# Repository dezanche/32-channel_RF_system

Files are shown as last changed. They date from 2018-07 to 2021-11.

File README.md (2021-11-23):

The 32-Channel RF Signal Amplifier and Attenuator System is a modular amplifier and attenuation system designed to provide 2nd stage amplification in close proximity to an MRI scanner. With proper choice of components it can readily be adapted to a wide range of Larmor frequencies and applications. Each channel’s amplifier and attenuator circuitry is housed on a separate daughterboard for flexibility and easy servicing.
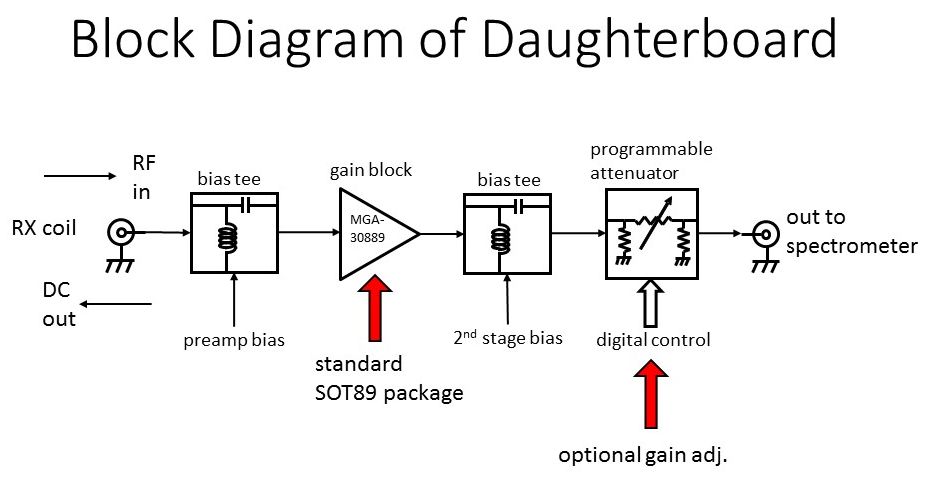
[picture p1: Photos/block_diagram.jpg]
block diagram

These Daughterboards stand perpendicular to a larger Motherboard which contains all the common circuitry such as power distribution and protection circuitry, as well as the interface for attenuation control.
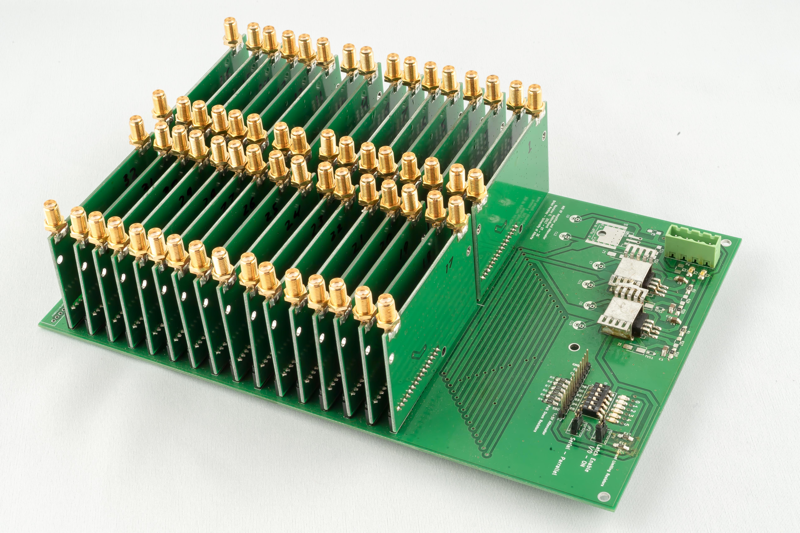
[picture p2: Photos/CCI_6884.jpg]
assembled boards

Additional information is provided in [this YouTube video](https://www.youtube.com/watch?v=jpFOpedchC8).

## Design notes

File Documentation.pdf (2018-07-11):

32-channel RF System | 1 | 2018-07-11

# 32-Channel RF Signal Amplifier and Attenuator System

## Design and Theory of Operation

## © 2018 Brian D. Markley and Nicola De Zanche University of Alberta

### Table of Contents

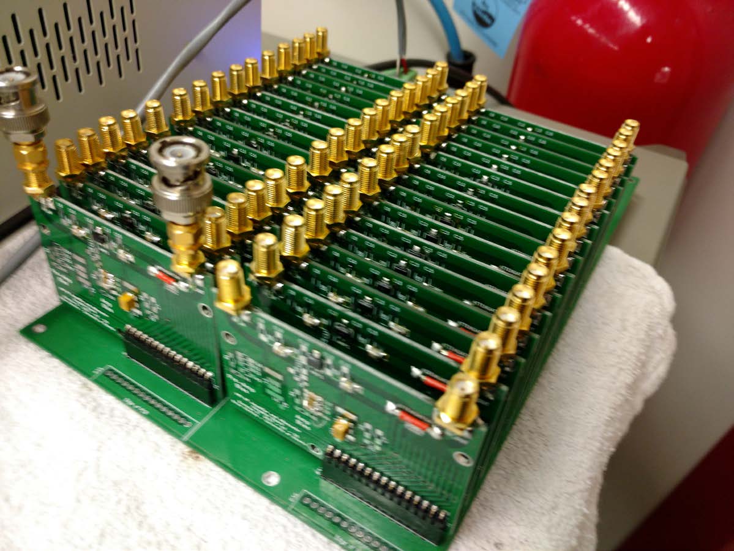
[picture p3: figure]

32-channel RF System | 2 | 2018-07-11

## Introduction

The 32-Channel RF Signal Amplifier and Attenuator System is a modular amplifier and attenuation system designed to provide 2nd stage amplification in close proximity to a 4.7 T MRI scanner (at a Larmor frequency
of 200 MHz). With proper choice of
components it can readily be adapted
to a wide range of other frequencies and applications. Each channel’s amplifier and attenuator circuitry is housed on a separate daughterboard for flexibility and easy servicing.
These | Daughterboards | stand
perpendicular | to | a | larger
Motherboard which contains all the common circuitry such as power distribution and protection circuitry, as well as the interface for attenuation control (Figure 1).

## License and Disclaimer

This open-source hardware design is licensed under the terms of the CERN
Open Hardware Licence v1.2 (https://www.ohwr.org/licenses/cern-ohl/license_versions/v1.2) (see also
License below). Specifically, the
design is provided “as is”, with no express or implied warranty, and the Licensor shall not be held liable for any damages resulting from the use of the design information.
The static magnetic field of the MRI scanner can cause dangerous forces on ferromagnetic materials. The instructions contained in this document require familiarity with MRI electronics and with the MRI environment. Standard precautions for working with such equipment must be followed. Specifically, all materials, tools and components used in construction must be non-magnetic if they are to be used within the MRI suite.

## Design

Principle of Operation
The 32-Channel RF Signal Amplifier and Attenuator System is designed to provide, for each channel, RF amplification using a single device (gain block), followed by an optional programmable attenuator to allow the signal level to be adjusted depending on the requirements of the subsequent stage (in this case the MRI scanner’s spectrometer). The design is modular, expandable and readily serviceable by using a separate board for each channel, laid out in an array on a single backplane (motherboard). The use of separate boards also provides high isolation (low crosstalk) between channels. A block diagram of one RF channel is shown in Figure 2.
The Motherboard distributes power and sets the attenuator states of up to 32 Daughterboards. Multiple motherboards can be daisy-chained if more than 32 channels are needed, taking care not to exceed the maximum current limits. Depending on the

Figure 1: The 32-Channel RF Signal Amplifier and Attenuator System. Note the daughterboard modules assembled in an array attached to the motherboard.

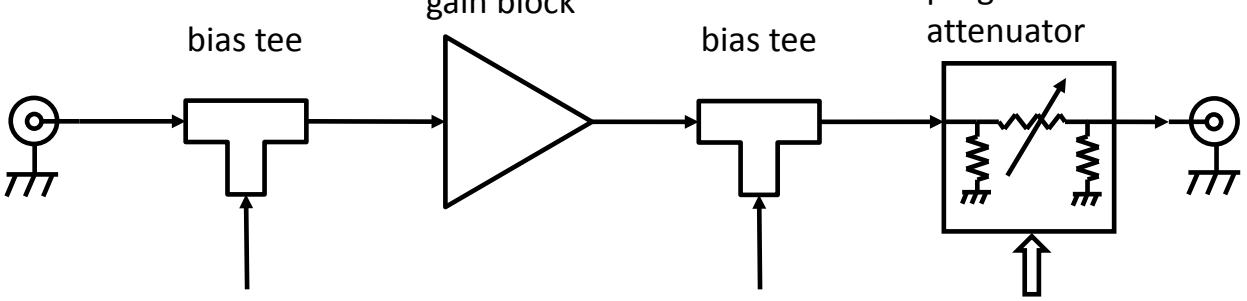
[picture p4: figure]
bias tee; attenuator

32-channel RF System | 3 | 2018-07-11

application’s requirements and component selection, some components (marked “optional” on the schematics) may be omitted. Board design follows IPC standards [1].

Motherboard
The motherboard contains all the power and control inputs for the amplifiers and attenuators. The daughter boards interface with the motherboard using female 2.54 mm straight pin headers on the motherboard and male 2.54 mm right-angle headers on the daughterboard. The motherboard is a 1.6 mm thick two-layer FR4 printed circuit board (PCB), plated with 2 ounce copper (70 µm) to limit the resistance of the traces. Schematics are shown in Figure 3 and Figure 4. The PCB layout is shown in Figure 5.

### Power

Power for 3 separate DC rails is provided through a 4-pin connector (P1). The rails supply, respectively, the RF amplifiers, attenuators, and optional external 1st stage amplifiers (e.g., for preamps at the RF coil) through a bias voltage at RF input of each DaughterBoard.
In our application the rails are all 5 volts, fed by an external 6.5 volt power supply, which is located outside of the MRI scanner room. Each power input is protected by 1 A resettable fuses (F1–F3), and if desired can be regulated (in our case to 5 volts) using 1084 voltage regulators (U1–U6, dual footprints are provided depending on package choice). The power regulators must be adequately heat-sinked to prevent failure. The design includes holes for bolt-on heat sinks as well as footprints for surface mount heat sinks on both the front and back of the board.
Capacitors (C1–C12) and resistors (R27–R32) for the power regulators must be used according to the regulator’s documentation. Additional footprints are provided on the board for optional power filtering components. Redundant footprints for both through-hole and surface-mount components are available on the PCB for flexibility in component choice and implementation.
Protection against overvoltage and electrostatic discharge (ESD) is provided by Zener (Z1–Z3) and transient-voltage-suppression (TVS) diodes (TVS1–TVS3), respectively [2]. Reverse polarity protection can be provided at the input of the voltage regulator by shunting to ground using an appropriately-rated reverse polarity diode. If the polarity is correct the diode will

Figure 2: Block diagram of one channel of the RF amplifier and attenuator system. RF signal flow is left to right.

gain block | programmable
preamp bias | 2nd stage bias | digital control

32-channel RF System | 4 | 2018-07-11

carry negligible current, but if polarity is reversed it will shunt current to ground, activating the fuse and protecting components downstream.

### Control

The control and interface components for the SKY12347-362LF attenuators are located on the motherboard. Manual control of these 6 bit attenuators is provided by 6 SPST switches (DIP1) and on-board jumpers for the latch enable (LE, JP1) and parallel-serial (P/S, JP2) interface selection. Remote attenuator control is available via a parallel or serial interface through the header (P2) located above the attenuator control switches.
Due to limitations in the P/S selection of the attenuator, parallel operation of the chip requires that the LE pin be switched high (5 V) after the power to the chip is brought high. To accommodate this, the current limiting resistor for the LE pin (R18) should use a large value (e.g., 1 MΩ) to provide a time delay on the LE pin. In this configuration the attenuator bits are set directly by either manual control with the motherboard switches, or – with the switches in the off position – remotely using the attenuator control header (P2) on the motherboard located above the switches.
Alternatively, remote control of the attenuator state can be controlled using a serial interface, by setting the P/S pin high and following the manufacturer’s documentation. The serial interface has the additional advantage of providing feedback of the attenuator state to a computer using the Serial Out pin (SO). This remote attenuation is not provided, but would be easily implemented with a separate module connected to the attenuator control header (P2).

### LED Indicators

The status of each power rail and attenuator bit is indicated using low-current LEDs (D1–D9) in series with resistors (R1–R9).

### Expandability

Multiple motherboards may be daisy-chained using the headers at the bottom edge of the PCB (P35 and P36) to expand the design to accommodate additional channels. If this is done, each PCB should be fed its power separately and only the attenuator circuitry should be interconnected. Maximum current on the attenuator traces is 1 A, and may need to be appropriately fused in case an accidental fault should occur.

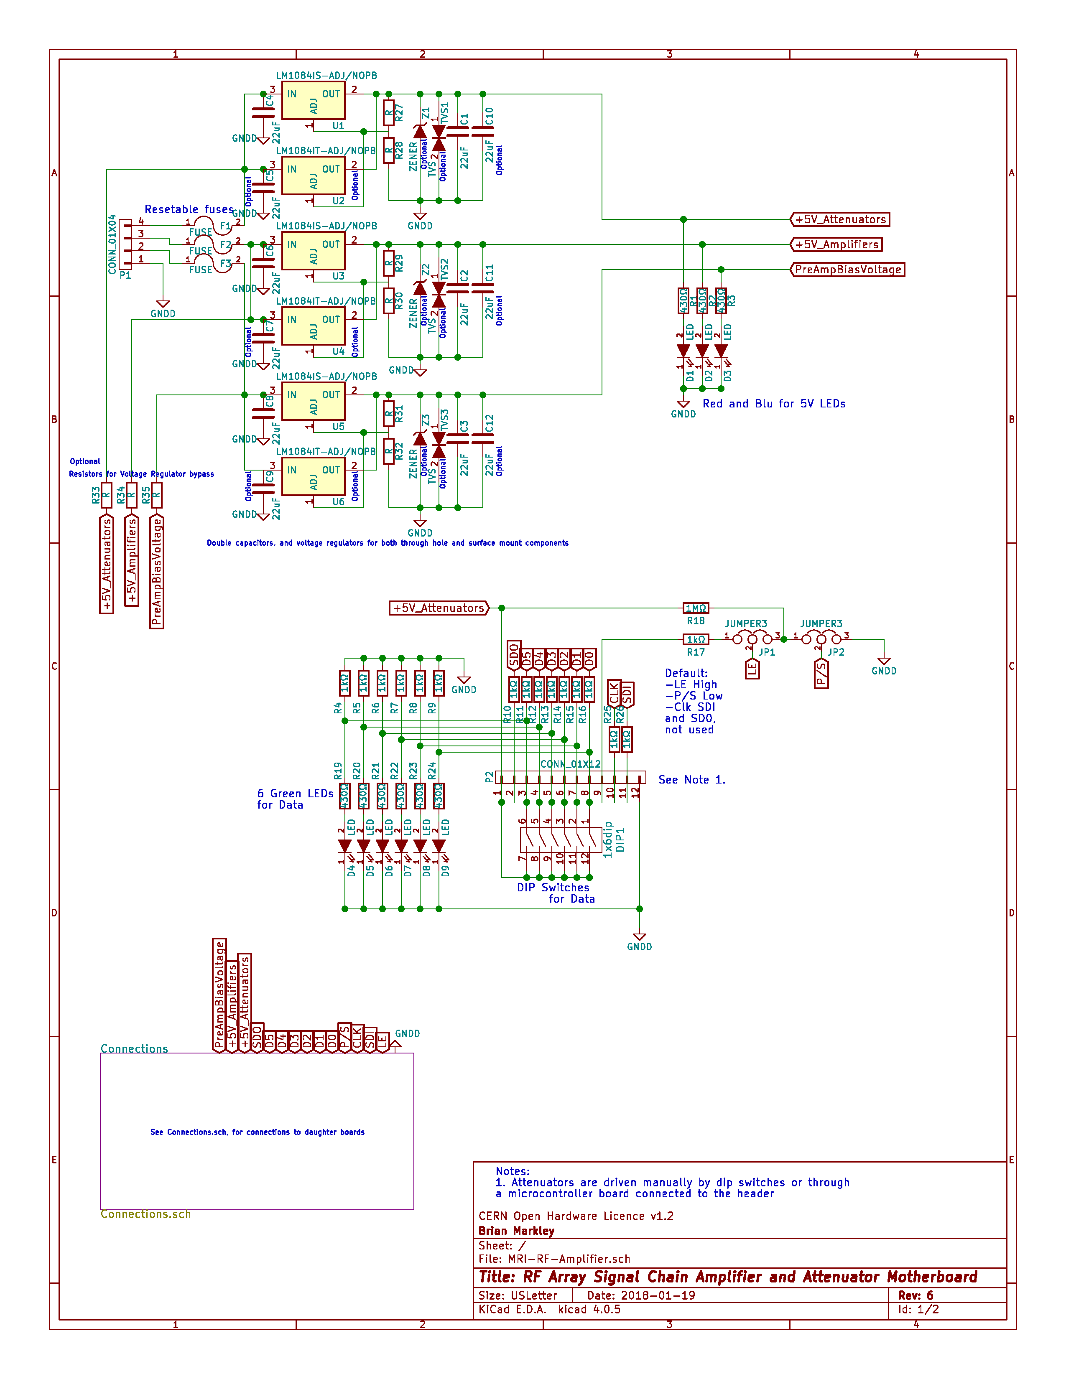
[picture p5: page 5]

32-channel RF System | 5 | 2018-07-11

Figure 3: Schematic of Motherboard power (top) and attenuator control circuitry (middle).

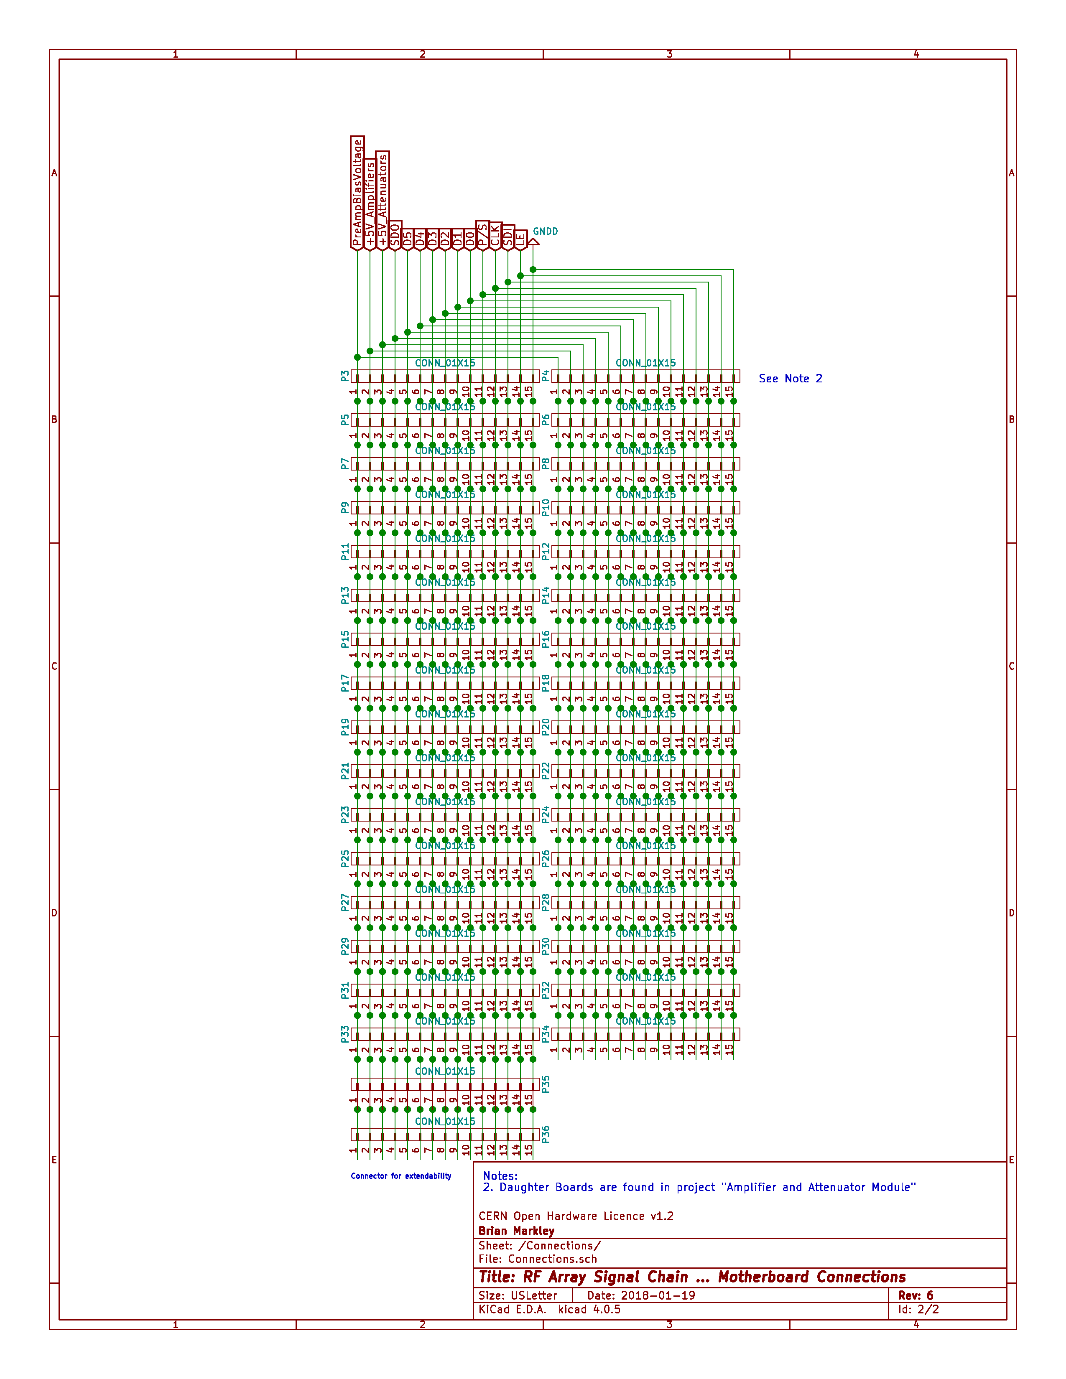
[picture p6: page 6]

32-channel RF System | 6 | 2018-07-11

Figure 4: Schematic of the Motherboard header array.

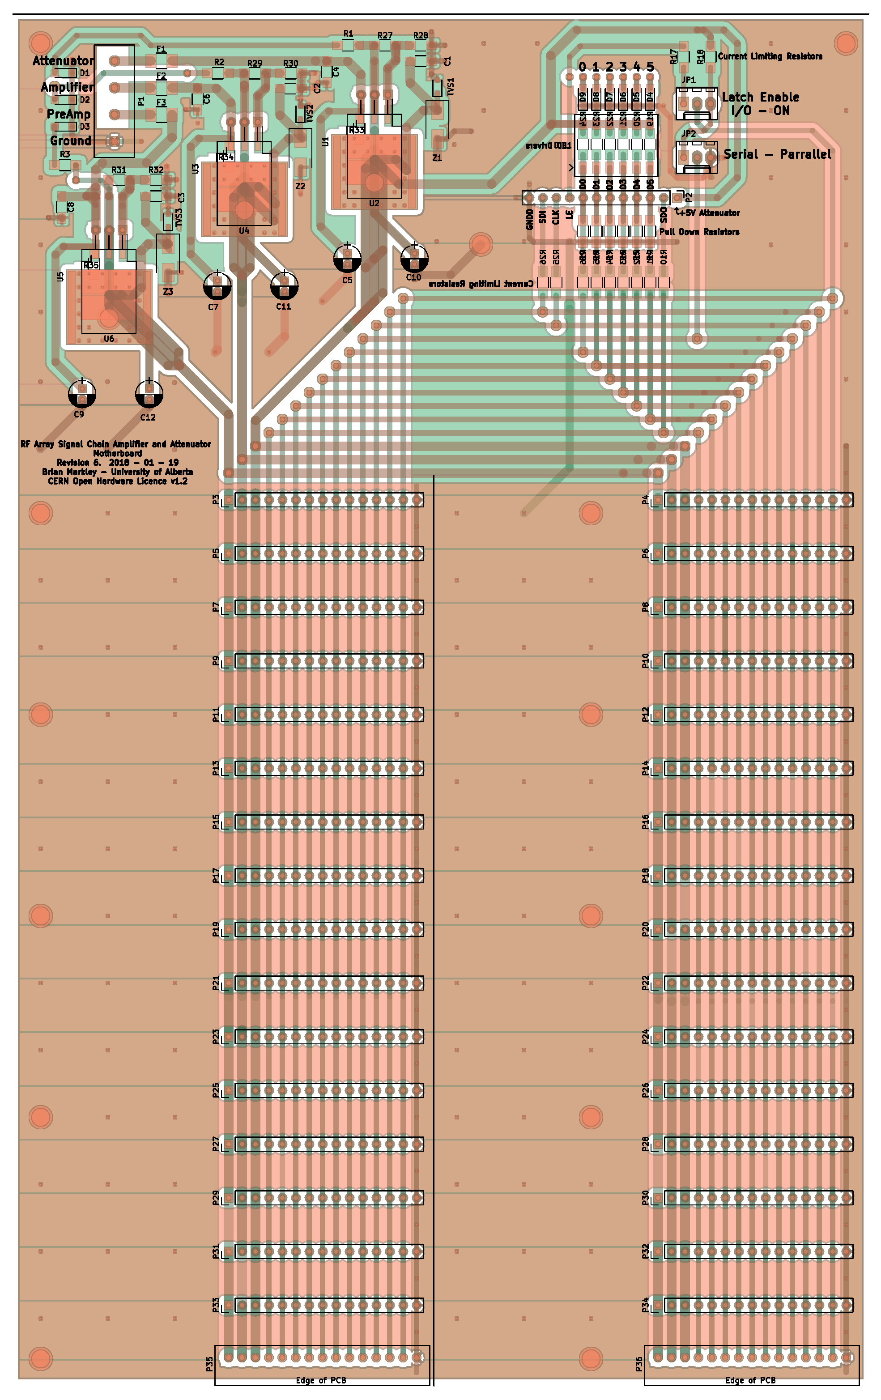
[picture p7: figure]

32-channel RF System | 7 | 2018-07-11

Figure 5: Motherboard PCB layout.

32-channel RF System | 8 | 2018-07-11

Daughterboards
Each daughterboard contains an amplifier (gain block) and attenuator, as well as a bias tee for providing DC bias to an external 1st stage amplifier (preamp). To minimize PCB cost from our supplier, the design includes two identical boards on a standard half eurocard size (80 mm × 100 mm), with a v-score where they can be separated. The PCB is a two-layer design on a 1.6 mm thick FR4 substrate with 1 ounce copper (35 µm). The schematic and the PCB layout are included in Figure 6 and Figure 7, respectively.

### RF Transmission Line

A coplanar waveguide with ground was used with the grounds designed to act primarily as a shielding element. The gap between the ground and RF line is 3.0 mm, and the RF line is 3.0 mm wide, which produces a transmission line with a characteristic impedance of 50 Ω, at 200 MHz (calculated using the transmission line calculator included with KiCAD). Using a separate board for each channel ensures that the length and shape of the transmission lines, and thus frequency and phase response for each channel, are identical. Input and output RF connections on each board can be made using a variety of end-launch coaxial connectors (RF1 and RF2) for 1.6 mm boards such as SMA.

### Amplification

Broadcom MGA-30889 amplifiers (AMP1) were selected for this design due to their high gain, and stability with a relatively low noise figure [3]. This device is now listed as “end-of-life” and will become obsolete. However, by using a standard SOT89-3 package, a wide variety of alternate amplifiers (gain blocks) is available for replacement. If the system is to be used in a location with significant static magnetic field (B0), the amplifiers’ performance should be measured in such conditions to ensure adequate performance. In many cases it is sufficient to rotate the orientation of the amplifiers relative to B0 to restore performance equivalent to the zero-field case. Footprints for optional components are available to allow for filtering and matching needs of various amplifiers that use the SOT89 footprint. Pads for low-current LEDs (D1–D3) and associated current-limiting resistors (R1, R4, R5) are provided to allow visual confirmation of power states if desired.

### Bias Tees

The amplifiers are powered using a DC bias tee (L3 or L4 and neighboring capacitors) to inject DC into the RF output pin. A pre-amplifier located closer to the MRI RF coil may also be powered through the optional pre-amp DC bias tee (L1 or L2 and neighboring capacitors), upstream from the on-board amplifier. If possible, inductors should be chosen to have a self-resonance frequency (SRF) close to the Larmor frequency of operation. Like all other components in the design, inductors for the DC bias tees must be air-core, phenolic-core, or other non-magnetic types if they are to be exposed to the static magnetic field of the MRI scanner. Those containing ferromagnetic materials will saturate and present a much lower inductance than the nominal value.

### Attenuation

A 6-bit SKY12347-362LF attenuator¹ (ATTENUATOR1) was selected for the design due to its relatively economical cost and 31.5 dB range of operation with 0.5 dB resolution [4]. This robust chip is controllable by either a serial or parallel interface. For parallel use the jumpers

1 currently listed by the manufacturer as “not recommended for new designs”. A drop-in alternate device has not been found.

32-channel RF System | 9 | 2018-07-11

on the motherboard need to be set to parallel mode (P/S pin set low) and the latch enable to ON (LE pin set high) as described in Control. The design may also be implemented without attenuators by soldering a short insulated wire across the attenuator’s footprint to join input and output RF traces. This was done on the prototype with good results.

### Interfacing and Mounting

The attenuator control and power connections interface with the Motherboard using a right-angle male 2.54 mm header (P1). The RF signal input and output interface to coaxial cables using end-launch connectors such as SMA or others having similar footprints. Note that forces on these connectors can be enough to displace the daughterboards because the header alone is not rigid enough to provide strong mounting. Therefore, it is recommended that additional mechanical supports be provided using the mounting holes or using bulkhead-type RF connectors secured to a plate that is perforated to accommodate all 64 RF connections. Care should also be taken to ensure that the daughterboards are not mated to the motherboard in the reverse orientation or with only a partial number of pins inserted (e.g., headers shifter by 1). No protection is provided against mating errors and damage may result to the Motherboard and/or Daughterboards.

### Futureproofing

The design is meant to be flexible so that the boards can be easily swapped out for maintenance or modification. Likewise, the daughterboard could be used independently of the motherboard as a single-channel device, although it may require power and protection circuitry external to the board. The amplifier SOT89 package is very common for gain blocks available from a variety of manufacturers, thus providing ample flexibility to the design. However, the QFN footprint of the attenuator is not commonly used – and there appears to be no drop-in replacement for this component. For this reason the daughterboard design may need to be modified for a different attenuator or if the current one becomes obsolete and is replaced with a newer model.

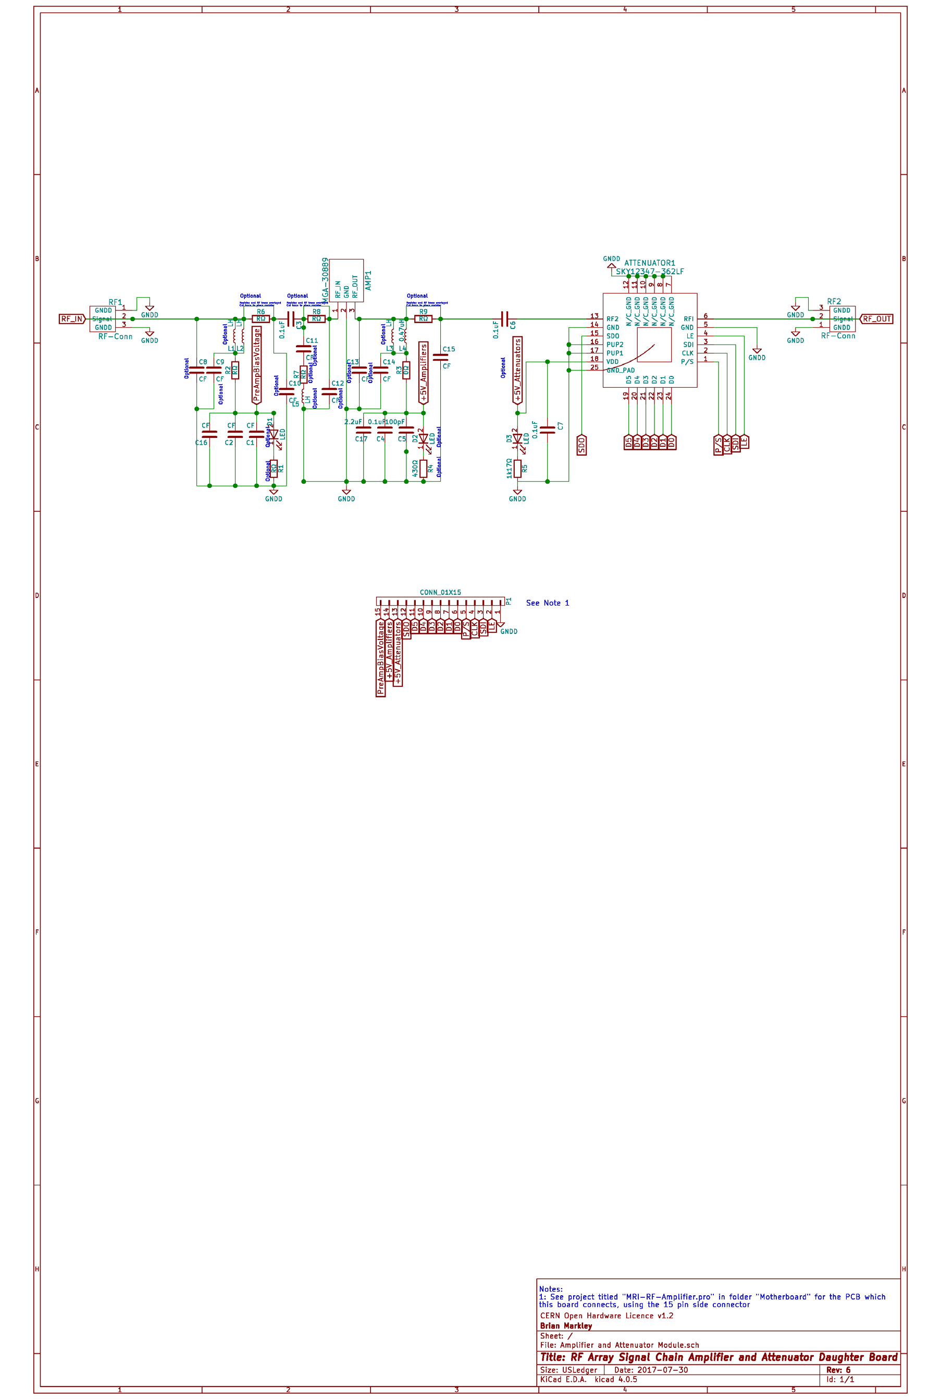
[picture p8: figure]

32-channel RF System | 10 | 2018-07-11

Figure 6: Schematic of the Daughterboards.

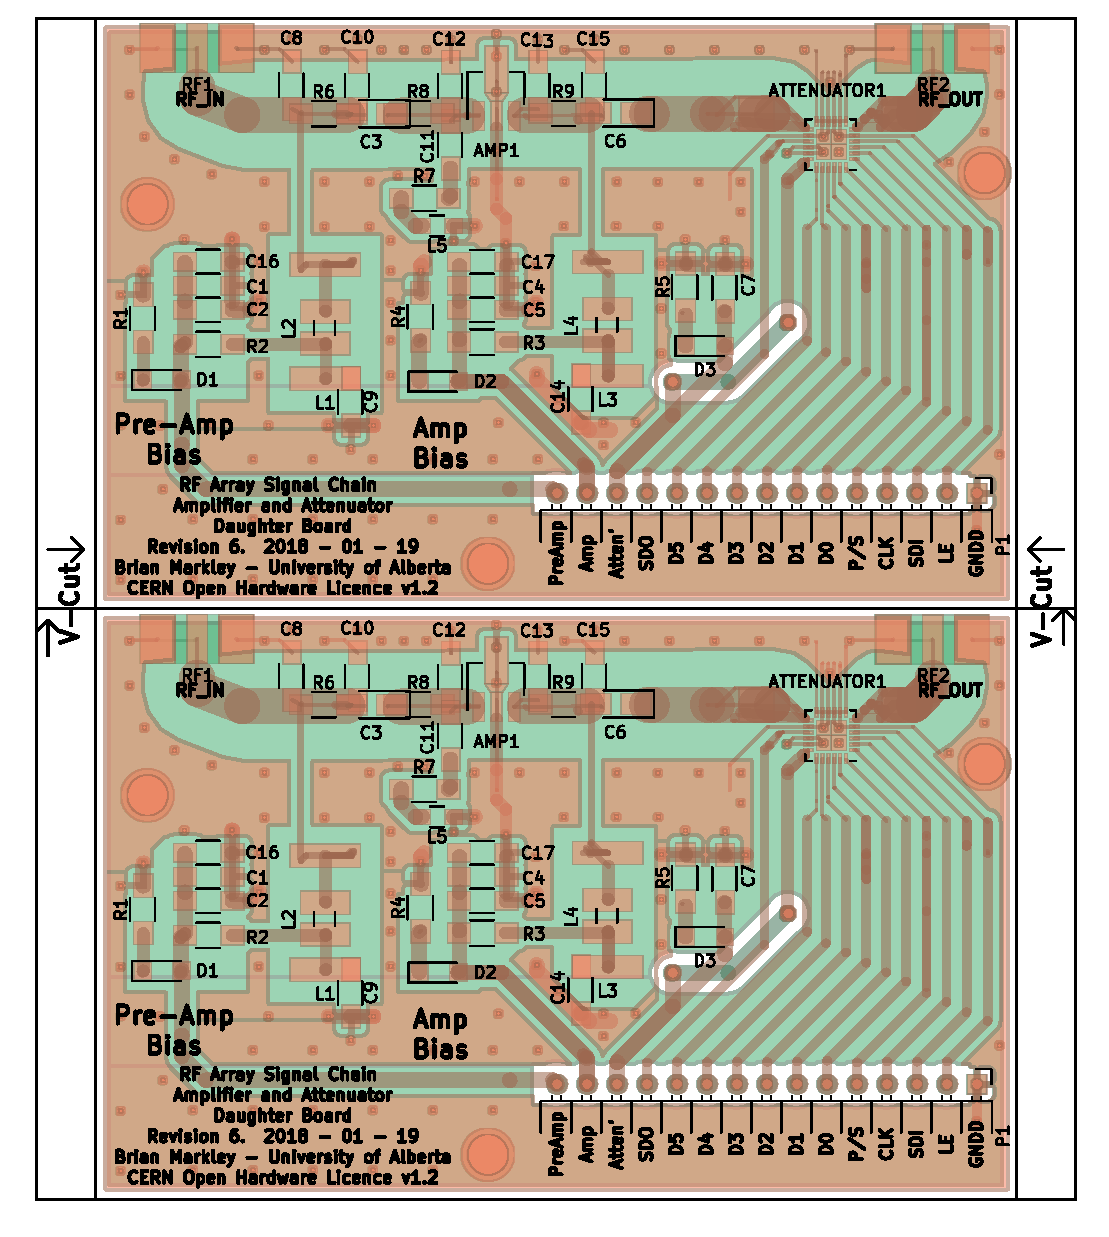
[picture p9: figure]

32-channel RF System | 11 | 2018-07-11

Figure 7: PCB Layout of Daughterboards.

32-channel RF System | 12 | 2018-07-11

## Performance as Built

The following tables summarize the performance of the system as built using the listed components. Performance using different components will vary.
Absolute Maxima
Amplifier and Attenuator Voltage MotherBoard | 7 | volts
Amplifier Current MotherBoard | 4 | amps
Attenuator Current MotherBoard | 1 | amp
RF Input DaughterBoard | 20 | dBm
Amplifier Voltage DaughterBoard | 5.5 | volts
Attenuator Voltage (Power and Control) | 6.0 | volts

Specifications
S21 (Gain) @ 200 MHz and -15 dBm VNA output | 15.4 | decibels
S11 @ 200 MHz and -15 dBm VNA output | -19 | decibels
S22 @ 200 MHz and -15 dBm VNA output | -15 | decibels
S12 @ 200 MHz and -15 dBm VNA output | -20 | decibels
Maximum Attenuation | 31.5 | decibels
Attenuation increment | 0.5 | decibels
Attenuator Voltage Input | 5 | volts
Amplifier Voltage Input | 5 | volts
Control Voltage | 5 | volts

## Design Package Details

The complete package for this design is available for download from https://github.com/dezanche/MRI_RF_hardware. In addition to this document it contains the license, PCB design, parts lists and component files for motherboard and daughterboards. License
This hardware design is provided under the terms of the CERN Open Hardware Licence v1.2 (https://www.ohwr.org/licenses/cern-ohl/license_versions/v1.2) (available online at https://www.ohwr.org/licenses/cern-ohl/license_versions/v1.2) and any subsequent updates. Modifications of this design are allowed provided that the Licensee makes the modified documentation publicly available. The original repository is an appropriate location to publish such updated documentation.
According to §4.2 of the license, the authors kindly request “information about the type, quantity and dates of production of Products the Licensee has (had) manufactured” based on this design.

32-channel RF System | 13 | 2018-07-11

PCB Files
The “MotherBoard” and “Amplifier and Attenuator Module” Folders contains the PCB design files, PDFs, and PCB production files (Gerber and drill files) – for the motherboard, and daughterboard. The PCB designs were produced using KiCAD (http://kicad-pcb.org/), which is free, open-source software.
Parts
In the “Parts” folder there are parts lists for both PCBs, lists of compatible amplifiers, and datasheets for both the amplifier and attenuator.

## Acknowledgements

This design is a fork of a “Capstone” engineering team design project that included Luona Zhang, Tae Young Choi, and Joshua Fisher in addition to BDM. We thank Lukas Winter for helpful discussions on the topic of licensing, and acknowledge funding from the Natural Sciences and Engineering Research Council of Canada (grant RGPIN 04844).

## References

[1] IPC. Generic Standard on Printed Board Design. IPC Standard 2221B, 2012
[2] Sarbishaei H. Electrostatic Discharge Protection Circuit for HighSpeed Mixed-Signal Circuits, Ph.D. thesis: Univ. of Waterloo, Waterloo, ON, Canada, 2007.
[3] Avago Technologies. MGA-30889 Datasheet, 2013.
[4] SKYWORKS. SKY12347-362LF DC-3.0 GHz Six-Bit Digital Attenuator with Serial or Parallel Driver Datasheet, 2011.

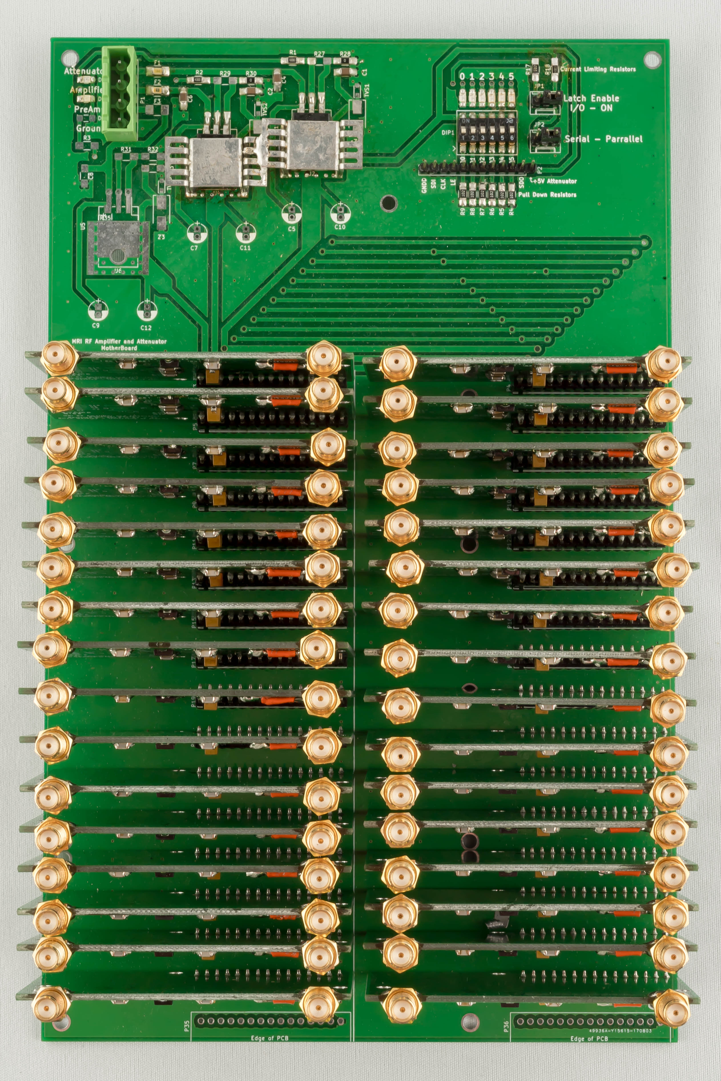
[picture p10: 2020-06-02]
Photos/CCI_6892.jpg

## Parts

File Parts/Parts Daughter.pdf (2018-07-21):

Schematic ID | Footprint | Part Name | Manufacturer | Supplier | Datasheet | Website | Quantity | Populated
AMP1 | SOT89-3 | MGA-30889 | Broadcom | Mouser | 1 | 1 (http://www.mouser.com/ds/2/678/V02-2250EN_DS_MGA-30889_2013-11-110-909140.pdf)
ATTENUATOR1 | QFN 4x4 | SKY12347-362LF | Skyworks | Mouser | 1 | 1 (http://ca.mouser.com/ProductDetail/Skyworks/SKY12347-362LF/)
C1, C4 | 1206 (3216) | 100nF Ceramic COG (GRM31C5C1H104JA01L) | Murata | LCSC | 2 | 1 (https://datasheet.lcsc.com/szlcsc/Multilayer-Ceramic-Capacitors-MLCC-SMD-SMT_muRata_GRM319R71H104KA01D_100nF-104-10-50V_C86047.pdf)
C2, C5 | 1206 (3216) | 100pF Ceramic COG (1206CG101J500NT) | Fenghua | LCSC | 2 | 1 (https://datasheet.lcsc.com/szlcsc/Multilayer-Ceramic-Capacitors-MLCC-SMD-SMT_FH_1206CG101J500NT_100pF-101-5-50V_C1884.pdf)
C3, C6 | 1206 (3216) | 100nF Ceramic COG (GRM31C5C1H104JA01L) | Murata | LCSC | 2 | 1 (https://datasheet.lcsc.com/szlcsc/Multilayer-Ceramic-Capacitors-MLCC-SMD-SMT_muRata_GRM319R71H104KA01D_100nF-104-10-50V_C86047.pdf)
C7 | 1206 (3216) | 100nF Ceramic COG (GRM31C5C1H104JA01L) | Murata | LCSC | 2 | 1 (https://datasheet.lcsc.com/szlcsc/Multilayer-Ceramic-Capacitors-MLCC-SMD-SMT_muRata_GRM319R71H104KA01D_100nF-104-10-50V_C86047.pdf)
C8 – C15, R6 – R9 | 1206 (3216) | For Amp Bias Future Proofing | 12 | 0
C16,C17 | 1206 (3216) | 2.2uF Ceramic Xr7 (CC1206KKX7R7BB225) | YAGEO | LCSC | 2 | 1 (https://datasheet.lcsc.com/szlcsc/Multilayer-Ceramic-Capacitors-MLCC-SMD-SMT_YAGEO_CC1206KKX7R7BB225_2-2uF-225-10-16V_C107183.pdf)
D1 | 1206 (3216) | LED Yellow | 1 | 0
D1 | 1206 (3216) | LED 2mA Red | ReliaPro | LCSC | 1 | 0 (https://datasheet.lcsc.com/szlcsc/Light-Emitting-Diodes-LED_ReliaPro_KT-1206Red-LED_LEDBright-red-light-1206_C49018.pdf)
D2 | 1206 (3216) | LED 2mA Blue | KENTO | LCSC | 1 | 0 (https://datasheet.lcsc.com/szlcsc/Light-Emitting-Diodes-LED_KENTO_1206B_SMDSMD-1206-blue_C72691.pdf)
L1, L3 | user defined | 100uH | 2 | 0
L2, L4 | 1812 (4532) | 0.47uH non magnetic 0.8ohm (IMC1812ERR47K) Vishay | Mouser | 2 | 1 (http://ca.mouser.com/Search/ProductDetail.aspx)
L5 | 0805 (2012) | For Amp Bias Future Proofing | 1 | 0
P1 | 2.54mm pitch 1x15 | 2.54mm 1x40P Reverse Bending Headers | ReliaPro | LCSC | 0.5 | 0.5 (https://datasheet.lcsc.com/szlcsc/Male-Header_ReliaPro_2-54mm-140P-Reverse-bending-HeadersPins_2-54mm-140P-Reverse-bending-HeadersPins_C29775.pdf)
R1 | 1206 (3216) | Resistor LED Drivers | 1 | 0
R2, R3 | 1206 (3216) | Amp Bias 0ohm (1206W4J0000T5E) | UniOhm | LCSC | 2 | 1 (https://datasheet.lcsc.com/szlcsc/Chip-Resistor-Surface-Mount-UniOhm_UniOhm_1206W4J0000T5E_0-0R0-5_C39126.pdf)
R4, R5 | 1206 (3216) | Resistor LED Drivers | 2 | 0
RF1, RF2 | SMA Edge Connectors | PinkPinkADay | Aliexpress | 2 | 2
PCB | Daughter Board | EasyEDA | EasyEDA | 1 | 1

Unpopulated (optional)

http://www.mouser.com/ds/2/678/V02-2250EN_DS_MGA-30889_2013-11-110-909140.pdf http://ca.mouser.com/Search/ProductDetail.aspx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 http://ca.mouser.com/ProductDetail/Skyworks/SKY12347-362LF/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 https://lcsc.com/product-detail/Multilayer-Ceramic-Capacitors-MLCC-SMD-SMT_muRata_GRM31C5C1H104JA01L_100nF-104-5-50V_C97946.htmlhttps://datasheet.lcsc.com/szlcsc/Mul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 https://lcsc.com/product-detail/Multilayer-Ceramic-Capacitors-MLCC-SMD-SMT_FH_1206CG101J500NT_100pF-101-5-50V_C1884.htmlhttps://datasheet.lcsc.com/szlcsc/Multilayer-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 https://lcsc.com/product-detail/Multilayer-Ceramic-Capacitors-MLCC-SMD-SMT_muRata_GRM31C5C1H104JA01L_100nF-104-5-50V_C97946.htmlhttps://datasheet.lcsc.com/szlcsc/Mul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 https://lcsc.com/product-detail/Multilayer-Ceramic-Capacitors-MLCC-SMD-SMT_muRata_GRM31C5C1H104JA01L_100nF-104-5-50V_C97946.html

https://datasheet.lcsc.com/szlcsc/Multilayer-Ceramic-Capacitors-MLCC-SMD-SMT_YAGEO_CC1206KKX7R7BB225_2-2uF-225-10-16V_C107183.pdf https://lcsc.com/product-detail/Multilayer-Ceramic-Capacitors-MLCC-SMD-SMT_YAGEO_CC1206KKX7R7BB225_2-2uF-225-10-16V_C107183.html

https://datasheet.lcsc.com/szlcsc/Light-Emitting-Diodes-LED_ReliaPro_KT-1206Red-LED_LEDBright-red-light-1206_C49018.pdf https://lcsc.com/product-detail/Light-Emitting-Diodes-LED_ReliaPro_KT-1206Red-LED_LEDBright-red-light-1206_C49018.htmlhttps://datasheet.lcsc.com/szlcsc/Light-Emittin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 https://lcsc.com/product-detail/Light-Emitting-Diodes-LED_KENTO_1206B_SMDSMD-1206-blue_C72691.html

http://www.mouser.com/ds/2/427/imc1812-239853.pdf http://ca.mouser.com/Search/ProductDetail.aspx?R=IMC1812ERR47Kvirtualkey61300000virtualkey70-IMC1812.4710%25TR

https://datasheet.lcsc.com/szlcsc/Male-Header_ReliaPro_2-54mm-140P-Reverse-bending-HeadersPins_2-54mm-140P-Reverse-bending-HeadersPins_C29775.pdf https://lcsc.com/product-detail/Male-Header_ReliaPro_2-54mm-140P-Reverse-bending-HeadersPins_2-54mm-140P-Reverse-bending-HeadersPins_C74252.html

https://datasheet.lcsc.com/szlcsc/Chip-Resistor-Surface-Mount-UniOhm_UniOhm_1206W4J0000T5E_0-0R0-5_C39126.pdf https://lcsc.com/product-detail/Chip-Resistor-Surface-Mount-UniOhm_UniOhm_1206W4J0000T5E_0-0R0-5_C39126.html

https://easyeda.com/

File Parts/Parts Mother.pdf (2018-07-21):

Sheet1

Page 1

Schematic ID | Footprint | Part Name | Manufacturer | Supplier | Datasheet | Website | Quantity | Populated
C1 -C4 , C6 , C8 | 1206 (3216) | 22uF X7R 16V(1206B226K160NT) | FH | LCSC | 6 | 6 (https://datasheet.lcsc.com/szlcsc/Multilayer-Ceramic-Capacitors-MLCC-SMD-SMT_FH_1206B104K251NT_100nF-104-10-250V_C1946.pdf)
C5, C7, C9 – C12 | 5x2 Radial Cap | 22uF (EM51EM220D05OT) | AISHI | LCSC | 6 | 0 (https://datasheet.lcsc.com/szlcsc/Aluminum-Electrolytic-Capacitors-Leaded_AISHI_EM51EM220D05OT_22uF-20-25V_C106443.pdf)
D1 | 1206 (3216) | LED 2mA Red | ReliaPro | LCSC | 1 | 1 (https://datasheet.lcsc.com/szlcsc/Light-Emitting-Diodes-LED_ReliaPro_KT-1206Red-LED_LEDBright-red-light-1206_C49018.pdf)
D2 | 1206 (3216) | LED 2mA Blue | KENTO | LCSC | 1 | 1 (https://datasheet.lcsc.com/szlcsc/Light-Emitting-Diodes-LED_KENTO_1206B_SMDSMD-1206-blue_C72691.pdf)
D3 | 1206 (3216) | LED 2mA Yellow | 1 | 0
D4,D5,D6,D7,D8,D9 | 1206 (3216) | LED 2mA Green | ReliaPro | LCSC | 6 | 6 (https://datasheet.lcsc.com/szlcsc/Light-Emitting-Diodes-LED_ReliaPro_led-Green_led-Green_C14641.pdf)
DIP1 | user | 2.54mm 6 DIP switch (DSIC06LSGET) | KE | LCSC | 1 | 1 (https://datasheet.lcsc.com/szlcsc/DIP-Switches_KE_DSIC06LSGET_2-54mm-6-DIP-switch_C54952.pdf)
F1 | 1210 (3225) | 1 amp Fast Acting | LittleFuse | LCSC | 1 | 1 (https://datasheet.lcsc.com/szlcsc/Surface-Mount-Fuses_Littelfuse_0437001-WR_1A-63V_C99537.pdf)
F2, F3 | 1210 (3225) | 4 amp Fast Acting | LittleFuse | LCSC | 2 | 1 (https://datasheet.lcsc.com/szlcsc/Surface-Mount-Fuses_Littelfuse_0437004-WR_4A-32V_C99540.pdf)
JP1, JP2 | 3x 2.54 pitch | ReliaPro | LCSC | 2 | 2 (https://datasheet.lcsc.com/szlcsc/Male-Header_ReliaPro_2-54mm-120PHeader_2-54mm-120P-Straight-HeadersPins_C50981.pdf)
2x1 jumper | 2x 2.54 pitch | 2.54mm Short hood | ReliaPro | LCSC | 2 | 2 (https://datasheet.lcsc.com/szlcsc/Shunts-Jumpers_ReliaPro_2-54mm-Short-hood_2-54mm-Short-hood_C5305.pdf)
P1 | 4x 5.08 pitch socket | WJ2EDGVC-5.08-4P | ReliaPro | LCSC | 1 | 1 (https://datasheet.lcsc.com/szlcsc/2EDG-Connectors_ReliaPro_WJ2EDGVC-5-08-4P_WJ2EDGVC-5-08-4P_C8436.pdf)
P1 | 4x 5.08 pitch ConnectorWJ2EDGKB-5.08-4P Connector | ReliaPro | LCSC | 1 | 1 (https://datasheet.lcsc.com/szlcsc/2EDG-Connectors_ReliaPro_WJ2EDGK-5-08-4P-14-00A_WJ2EDGK-5-08-4P_C71372.pdf)
P2 | 12x 2.54 pitch | ReliaPro | LCSC | 1 | 1 (https://datasheet.lcsc.com/szlcsc/Male-Header_ReliaPro_2-54mm-120PHeader_2-54mm-120P-Straight-HeadersPins_C50981.pdf)
P3 – P34 | 15x 2.54 pitch | ReliaPro | LCSC | 32 | 32 (https://datasheet.lcsc.com/szlcsc/Female-Header_ReliaPro_Female-header1X15P-2-54mm_Female-header-1X15P-2-54mm_C54104.pdf)
P35, P36 | 15x 2.54 pitch edge | 2 | 0
R1 | 1206 (3216) | 1 | 0
R4-R17, R25, R26 | 1206 (3216) | 1 Kohm Current Limters | FH | LCSC | 16 | 16 (https://datasheet.lcsc.com/szlcsc/Chip-Resistor-Surface-Mount_FH_RS-06K102JT_1K-102-5_C115421.pdf)
R18 | 1206 (3216) | 1 Mohm Current Limiter | FH | LCSC | 1 | 1 (https://datasheet.lcsc.com/szlcsc/Chip-Resistor-Surface-Mount-UniOhm_UniOhm_1206W4F4300T5E_430-4300-1_C17965.pdf)
R2, R3, R19 – R24 | 1206 (3216) | 430 ohm LED Drivers | Uniroyal | LCSC | 8 | 8 (https://datasheet.lcsc.com/szlcsc/Chip-Resistor-Surface-Mount-UniOhm_UniOhm_1206W4F4300T5E_430-4300-1_C17965.pdf)
R27, R29, R31 | 1206 (3216) | Voltage Divider High (R1 = 300 ohm) | FH | LCSC | 3 | 2 (https://datasheet.lcsc.com/szlcsc/Chip-Resistor-Surface-Mount-UniOhm_UniOhm_1206W4F3000T5E_300-3000-1_C17887.pdf)
R28, R30, R32 | 1206 (3216) | Voltage Divider Low (R2 = 100ohm) | UniOhm | LCSC | 3 | 2 (https://datasheet.lcsc.com/szlcsc/Chip-Resistor-Surface-Mount-UniOhm_UniOhm_1206W4F1000T5E_100-1000-1_C17901.pdf)
R33, R34, R35 | 1206 (3216) | 0ohm jumper for Voltage Regulator Bypass UniOhm | LCSC | 3 | 0 (https://datasheet.lcsc.com/szlcsc/Chip-Resistor-Surface-Mount-UniOhm_UniOhm_1206W4J0000T5E_0-0R0-5_C39126.pdf)
TVS1, TVS2, TVS3 | SOD323 | 3 | 0
U1, U3 | To-263-3 | UZ1084 | LCSC | 2 | 2 (https://datasheet.lcsc.com/szlcsc/Linear-Voltage-Regulators_UTC_UZ1084L-AD-TQ3-R_UZ1084L-AD-TQ3-R_C75490.pdf)
U5 | To-263-3 | AMS1084 | LCSC | 1 | 1 (https://datasheet.lcsc.com/szlcsc/Low-Dropout-Regulators-LDO_AMS_AMS1084CM-5-0_AMS1084CM-5-0_C56105.pdf)
U2, U4, U6 | T0-220 | LM1084 | LCSC | 3 | 0 (https://datasheet.lcsc.com/szlcsc/Low-Dropout-Regulators-LDO_TI_LM1084IT-ADJ_LM1084IT-ADJ_C9720.pdf)
Z1, Z2, Z3 | D-SMB | Zener Diodes | 3 | 0
HeatSink | To-263-3 – heatsinked 573300D00000G | Aavid | Mouser | 6 | 6 (http://ca.mouser.com/Search/ProductDetail.aspx)
PCB | EasyEDA | EasyEDA | 1 | 1

Unpopulated (optional)

https://datasheet.lcsc.com/szlcsc/Multilayer-Ceramic-Capacitors-MLCC-SMD-SMT_FH_1206B104K251NT_100nF-104-10-250V_C1946.pdf https://lcsc.com/product-detail/Multilayer-Ceramic-Capacitors-MLCC-SMD-SMT_FH_1206B226K160NT_22uF-10-16V_C31847.htmlhttps://datasheet.lcsc.com/szlcsc/Aluminum-Electr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 https://lcsc.com/product-detail/Aluminum-Electrolytic-Capacitors-Leaded_AISHI_EM51EM220D05OT_22uF-20-25V_C106443.htmlhttps://datasheet.lcsc.com/szlcsc/Light-Emitting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 https://lcsc.com/product-detail/Light-Emitting-Diodes-LED_ReliaPro_KT-1206Red-LED_LEDBright-red-light-1206_C49018.htmlhttps://datasheet.lcsc.com/szlcsc/Light-Emittin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 https://lcsc.com/product-detail/Light-Emitting-Diodes-LED_KENTO_1206B_SMDSMD-1206-blue_C72691.html

https://datasheet.lcsc.com/szlcsc/Light-Emitting-Diodes-LED_ReliaPro_led-Green_led-Green_C14641.pdf https://lcsc.com/product-detail/Light-Emitting-Diodes-LED_ReliaPro_led-Green_led-Green_C14641.htmlhttps://datasheet.lcsc.com/szlcsc/DIP-Switches_KE_DSIC06LSGET_2-54m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 https://lcsc.com/product-detail/DIP-Switches_KE_DSIC06LSGET_2-54mm-6-DIP-switch_C54952.htmlhttps://datasheet.lcsc.com/szlcsc/Surface-Mount-Fuses_Littelfuse_0437001-W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 https://lcsc.com/product-detail/Surface-Mount-Fuses_Littelfuse_0437001-WR_1A-63V_C99537.htmlhttps://datasheet.lcsc.com/szlcsc/Surface-Mount-Fuses_Littelfuse_0437004-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 https://lcsc.com/product-detail/Surface-Mount-Fuses_Littelfuse_0437004-WR_4A-32V_C99540.html
2.54mm 1*20P Straight Headers Pins | https://datasheet.lcsc.com/szlcsc/Male-Header_ReliaPro_2-54mm-120PHeader_2-54mm-120P-Straight-HeadersPins_C50981.pdf https://lcsc.com/product-detail/Male-Header_ReliaPro_2-54mm-120PHeader_2-54mm-120P-Straight-HeadersPins_C50981.html
| https://datasheet.lcsc.com/szlcsc/Shunts-Jumpers_ReliaPro_2-54mm-Short-hood_2-54mm-Short-hood_C5305.pdf https://lcsc.com/product-detail/Shunts-Jumpers_ReliaPro_2-54mm-Short-hood_2-54mm-Short-hood_C5305.html
| https://datasheet.lcsc.com/szlcsc/2EDG-Connectors_ReliaPro_WJ2EDGVC-5-08-4P_WJ2EDGVC-5-08-4P_C8436.pdf https://lcsc.com/product-detail/2EDG-Connectors_ReliaPro_WJ2EDGVC-5-08-4P_WJ2EDGVC-5-08-4P_C8436.html
| https://datasheet.lcsc.com/szlcsc/2EDG-Connectors_ReliaPro_WJ2EDGK-5-08-4P-14-00A_WJ2EDGK-5-08-4P_C71372.pdf https://lcsc.com/product-detail/2EDG-Connectors_ReliaPro_WJ2EDGK-5-08-4P-14-00A_WJ2EDGK-5-08-4P_C71372.html
2.54mm 1*12P Straight Headers Pins | https://datasheet.lcsc.com/szlcsc/Male-Header_ReliaPro_2-54mm-120PHeader_2-54mm-120P-Straight-HeadersPins_C50981.pdf https://lcsc.com/product-detail/Male-Header_ReliaPro_2-54mm-120PHeader_2-54mm-120P-Straight-HeadersPins_C50981.html
2.54mm 1*15P Straight Headers female Pins | https://datasheet.lcsc.com/szlcsc/Female-Header_ReliaPro_Female-header1X15P-2-54mm_Female-header-1X15P-2-54mm_C54104.pdf https://lcsc.com/product-detail/Female-Header_ReliaPro_Female-header1X15P-2-54mm_Female-header-1X15P-2-54mm_C54104.html
| https://datasheet.lcsc.com/szlcsc/Chip-Resistor-Surface-Mount_FH_RS-06K102JT_1K-102-5_C115421.pdf https://lcsc.com/product-detail/Chip-Resistor-Surface-Mount_FH_RS-06K102JT_1K-102-5_C115421.html
| https://datasheet.lcsc.com/szlcsc/Chip-Resistor-Surface-Mount-UniOhm_UniOhm_1206W4F4300T5E_430-4300-1_C17965.pdf https://lcsc.com/product-detail/Chip-Resistor-Surface-Mount-UniOhm_UniOhm_1206W4F4300T5E_430-4300-1_C17965.html
| https://datasheet.lcsc.com/szlcsc/Chip-Resistor-Surface-Mount-UniOhm_UniOhm_1206W4F4300T5E_430-4300-1_C17965.pdf https://lcsc.com/product-detail/Chip-Resistor-Surface-Mount-UniOhm_UniOhm_1206W4F4300T5E_430-4300-1_C17965.html
| https://datasheet.lcsc.com/szlcsc/Chip-Resistor-Surface-Mount-UniOhm_UniOhm_1206W4F3000T5E_300-3000-1_C17887.pdf https://lcsc.com/product-detail/Chip-Resistor-Surface-Mount-UniOhm_UniOhm_1206W4F3000T5E_300-3000-1_C17887.html
| https://datasheet.lcsc.com/szlcsc/Chip-Resistor-Surface-Mount-UniOhm_UniOhm_1206W4F1000T5E_100-1000-1_C17901.pdf https://lcsc.com/product-detail/Chip-Resistor-Surface-Mount-UniOhm_UniOhm_1206W4F1000T5E_100-1000-1_C17901.html
| https://datasheet.lcsc.com/szlcsc/Chip-Resistor-Surface-Mount-UniOhm_UniOhm_1206W4J0000T5E_0-0R0-5_C39126.pdf https://lcsc.com/product-detail/Chip-Resistor-Surface-Mount-UniOhm_UniOhm_1206W4J0000T5E_0-0R0-5_C39126.html
| https://datasheet.lcsc.com/szlcsc/Linear-Voltage-Regulators_UTC_UZ1084L-AD-TQ3-R_UZ1084L-AD-TQ3-R_C75490.pdf https://lcsc.com/product-detail/Linear-Voltage-Regulators_UTC_UZ1084L-AD-TQ3-R_UZ1084L-AD-TQ3-R_C75490.html
| https://datasheet.lcsc.com/szlcsc/Low-Dropout-Regulators-LDO_AMS_AMS1084CM-5-0_AMS1084CM-5-0_C56105.pdf https://lcsc.com/product-detail/Low-Dropout-Regulators-LDO_AMS_AMS1084CM-5-0_AMS1084CM-5-0_C56105.html
| https://datasheet.lcsc.com/szlcsc/Low-Dropout-Regulators-LDO_TI_LM1084IT-ADJ_LM1084IT-ADJ_C9720.pdf https://lcsc.com/product-detail/Low-Dropout-Regulators-LDO_TI_LM1084IT-ADJ_LM1084IT-ADJ_C9720.html
| https://www.aavid.com/products/standard/573300d00000g http://ca.mouser.com/Search/ProductDetail.aspx?R=573300D00000Gvirtualkey53210000virtualkey532-573300D00000G
| https://easyeda.com

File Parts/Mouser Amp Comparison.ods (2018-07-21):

Manufacturer | Name | Datasheet | Website | Gain (s21) @200Mhz (dB) | P1dB @ 200MHz (dBm) | OIP3 @200Mhz (dBm) | NF @200Mhz (dB) | Voltage (V) | Current (mA) | Price @ 35 qty | Notes
Qorvo | TQP3M9008 | http://www.triquint.com/products/d/DOC-A-00000762 | http://ca.mouser.com/ProductDetail/Qorvo/TQP3M9008/ | 23.5 | 20 | 36 | 0.8 | 5 | 85 | 5.17 | Amp Used for Old Design
Analog Devices | ADL5536 | http://www.mouser.com/ds/2/609/ADL5536-878582.pdf | http://ca.mouser.com/ProductDetail/Analog-Devices/ADL5536ARKZ-R7/?qs=sGAEpiMZZMv9Q1JI0Mo%2ftXcNxAAUx7z0 | 19.8 | 19.6 | 45 | 2.6 | 5 | 105 | 5.00 | Better OIP3, Worse NF
Analog Devices | ADL5544 | http://www.mouser.com/ds/2/609/ADL5544-916951.pdf | http://ca.mouser.com/ProductDetail/Analog-Devices/ADL5544ARKZ-R7/?qs=sGAEpiMZZMtUKTCHc2CNRLO4FQQn%252bMFJ | 18.1 | 16.9 | 32 | 3.1 | 5 | 55 | 3.86 | Worse
Analog Devices | ADL5545 | http://www.mouser.com/ds/2/609/ADL5545-916952.pdf | http://ca.mouser.com/ProductDetail/Analog-Devices/ADL5545ARKZ-R7/?qs=sGAEpiMZZMtUKTCHc2CNRKet9awLDa7E | 24.8 | 14.6 | 31.5 | 3.1 | 5 | 56 | 3.86 | Better GAIN, Worse NF
Broadcom | MGA30889 | http://www.datasheetspdf.com/mobile/855421/MGA-30889.html | http://ca.mouser.com/ProductDetail/Broadcom-Avago/MGA-30889-TR1G/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 | 15.8 | 20.9 | 40 | 1.9 | 5 | 65 | 3.17 | Cheapest Option. Low Gain OIP3 only 40 at 200 MHz, and 25C, otherwise 37

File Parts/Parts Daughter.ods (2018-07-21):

Schematic ID | Footprint | Part Name | Manufacturer | Supplier | Datasheet | Website | Quantity | Populated
AMP1 | SOT89-3 | MGA-30889 | Broadcom | Mouser | http://www.mouser.com/ds/2/678/V02-2250EN_DS_MGA-30889_2013-11-110-909140.pdf | http://ca.mouser.com/Search/ProductDetail.aspx | 1 | 1
ATTENUATOR1 | QFN 4x4 | SKY12347-362LF | Skyworks | Mouser | www.skyworksinc.com/uploads/documents/201371B.pdf | http://ca.mouser.com/ProductDetail/Skyworks/SKY12347-362LF/ | 1 | 1
C1, C4 | 1206 (3216) | 100nF Ceramic COG (GRM31C5C1H104JA01L) | Murata | LCSC | https://datasheet.lcsc.com/szlcsc/Multilayer-Ceramic-Capacitors-MLCC-SMD-SMT_muRata_GRM319R71H104KA01D_100nF-104-10-50V_C86047.pdf | https://lcsc.com/product-detail/Multilayer-Ceramic-Capacitors-MLCC-SMD-SMT_muRata_GRM31C5C1H104JA01L_100nF-104-5-50V_C97946.html | 2 | 1
C2, C5 | 1206 (3216) | 100pF Ceramic COG (1206CG101J500NT) | Fenghua | LCSC | https://datasheet.lcsc.com/szlcsc/Multilayer-Ceramic-Capacitors-MLCC-SMD-SMT_FH_1206CG101J500NT_100pF-101-5-50V_C1884.pdf | https://lcsc.com/product-detail/Multilayer-Ceramic-Capacitors-MLCC-SMD-SMT_FH_1206CG101J500NT_100pF-101-5-50V_C1884.html | 2 | 1
C3, C6 | 1206 (3216) | 100nF Ceramic COG (GRM31C5C1H104JA01L) | Murata | LCSC | https://datasheet.lcsc.com/szlcsc/Multilayer-Ceramic-Capacitors-MLCC-SMD-SMT_muRata_GRM319R71H104KA01D_100nF-104-10-50V_C86047.pdf | https://lcsc.com/product-detail/Multilayer-Ceramic-Capacitors-MLCC-SMD-SMT_muRata_GRM31C5C1H104JA01L_100nF-104-5-50V_C97946.html | 2 | 1
C7 | 1206 (3216) | 100nF Ceramic COG (GRM31C5C1H104JA01L) | Murata | LCSC | https://datasheet.lcsc.com/szlcsc/Multilayer-Ceramic-Capacitors-MLCC-SMD-SMT_muRata_GRM319R71H104KA01D_100nF-104-10-50V_C86047.pdf | https://lcsc.com/product-detail/Multilayer-Ceramic-Capacitors-MLCC-SMD-SMT_muRata_GRM31C5C1H104JA01L_100nF-104-5-50V_C97946.html | 2 | 1
C8 – C15, R6 – R9 | 1206 (3216) | For Amp Bias Future Proofing |  |  |  |  | 12 | 0
C16,C17 | 1206 (3216) | 2.2uF Ceramic Xr7 (CC1206KKX7R7BB225) | YAGEO | LCSC | https://datasheet.lcsc.com/szlcsc/Multilayer-Ceramic-Capacitors-MLCC-SMD-SMT_YAGEO_CC1206KKX7R7BB225_2-2uF-225-10-16V_C107183.pdf | https://lcsc.com/product-detail/Multilayer-Ceramic-Capacitors-MLCC-SMD-SMT_YAGEO_CC1206KKX7R7BB225_2-2uF-225-10-16V_C107183.html | 2 | 1
D1 | 1206 (3216) | LED Yellow |  |  |  |  | 1 | 0
D1 | 1206 (3216) | LED 2mA Red | ReliaPro | LCSC | https://datasheet.lcsc.com/szlcsc/Light-Emitting-Diodes-LED_ReliaPro_KT-1206Red-LED_LEDBright-red-light-1206_C49018.pdf | https://lcsc.com/product-detail/Light-Emitting-Diodes-LED_ReliaPro_KT-1206Red-LED_LEDBright-red-light-1206_C49018.html | 1 | 0
D2 | 1206 (3216) | LED 2mA Blue | KENTO | LCSC | https://datasheet.lcsc.com/szlcsc/Light-Emitting-Diodes-LED_KENTO_1206B_SMDSMD-1206-blue_C72691.pdf | https://lcsc.com/product-detail/Light-Emitting-Diodes-LED_KENTO_1206B_SMDSMD-1206-blue_C72691.html | 1 | 0
L1, L3 | user defined | 100uH |  |  |  |  | 2 | 0
L2, L4 | 1812 (4532) | 0.47uH non magnetic 0.8ohm (IMC1812ERR47K) | Vishay | Mouser | http://www.mouser.com/ds/2/427/imc1812-239853.pdf | http://ca.mouser.com/Search/ProductDetail.aspx | 2 | 1
L5 | 0805 (2012) | For Amp Bias Future Proofing |  |  |  |  | 1 | 0
P1 | 2.54mm pitch 1x15 | 2.54mm 1x40P Reverse Bending Headers | ReliaPro | LCSC | https://datasheet.lcsc.com/szlcsc/Male-Header_ReliaPro_2-54mm-140P-Reverse-bending-HeadersPins_2-54mm-140P-Reverse-bending-HeadersPins_C29775.pdf | https://lcsc.com/product-detail/Male-Header_ReliaPro_2-54mm-140P-Reverse-bending-HeadersPins_2-54mm-140P-Reverse-bending-HeadersPins_C74252.html | 0.5 | 0.5
R1 | 1206 (3216) | Resistor LED Drivers |  |  |  |  | 1 | 0
R2, R3 | 1206 (3216) | Amp Bias 0ohm (1206W4J0000T5E) | UniOhm | LCSC | https://datasheet.lcsc.com/szlcsc/Chip-Resistor-Surface-Mount-UniOhm_UniOhm_1206W4J0000T5E_0-0R0-5_C39126.pdf | https://lcsc.com/product-detail/Chip-Resistor-Surface-Mount-UniOhm_UniOhm_1206W4J0000T5E_0-0R0-5_C39126.html | 2 | 1
R4, R5 | 1206 (3216) | Resistor LED Drivers |  |  |  |  | 2 | 0
RF1, RF2 |  | SMA Edge Connectors | PinkPinkADay | Aliexpress |  |  | 2 | 2
PCB |  | Daughter Board | EasyEDA | EasyEDA |  | https://easyeda.com/ | 1 | 1
 |  | Unpopulated (optional)

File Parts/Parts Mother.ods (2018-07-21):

Schematic ID | Footprint | Part Name | Manufacturer | Supplier | Datasheet | Website | Quantity | Populated
C1 -C4 , C6 , C8 | 1206 (3216) | 22uF X7R 16V(1206B226K160NT) | FH | LCSC | https://datasheet.lcsc.com/szlcsc/Multilayer-Ceramic-Capacitors-MLCC-SMD-SMT_FH_1206B104K251NT_100nF-104-10-250V_C1946.pdf | https://lcsc.com/product-detail/Multilayer-Ceramic-Capacitors-MLCC-SMD-SMT_FH_1206B226K160NT_22uF-10-16V_C31847.html | 6 | 6
C5, C7, C9 – C12 | 5x2 Radial Cap | 22uF (EM51EM220D05OT) | AISHI | LCSC | https://datasheet.lcsc.com/szlcsc/Aluminum-Electrolytic-Capacitors-Leaded_AISHI_EM51EM220D05OT_22uF-20-25V_C106443.pdf | https://lcsc.com/product-detail/Aluminum-Electrolytic-Capacitors-Leaded_AISHI_EM51EM220D05OT_22uF-20-25V_C106443.html | 6 | 0
D1 | 1206 (3216) | LED 2mA Red | ReliaPro | LCSC | https://datasheet.lcsc.com/szlcsc/Light-Emitting-Diodes-LED_ReliaPro_KT-1206Red-LED_LEDBright-red-light-1206_C49018.pdf | https://lcsc.com/product-detail/Light-Emitting-Diodes-LED_ReliaPro_KT-1206Red-LED_LEDBright-red-light-1206_C49018.html | 1 | 1
D2 | 1206 (3216) | LED 2mA Blue | KENTO | LCSC | https://datasheet.lcsc.com/szlcsc/Light-Emitting-Diodes-LED_KENTO_1206B_SMDSMD-1206-blue_C72691.pdf | https://lcsc.com/product-detail/Light-Emitting-Diodes-LED_KENTO_1206B_SMDSMD-1206-blue_C72691.html | 1 | 1
D3 | 1206 (3216) | LED 2mA Yellow |  |  |  |  | 1 | 0
D4,D5,D6,D7,D8,D9 | 1206 (3216) | LED 2mA Green | ReliaPro | LCSC | https://datasheet.lcsc.com/szlcsc/Light-Emitting-Diodes-LED_ReliaPro_led-Green_led-Green_C14641.pdf | https://lcsc.com/product-detail/Light-Emitting-Diodes-LED_ReliaPro_led-Green_led-Green_C14641.html | 6 | 6
DIP1 | user | 2.54mm 6 DIP switch (DSIC06LSGET) | KE | LCSC | https://datasheet.lcsc.com/szlcsc/DIP-Switches_KE_DSIC06LSGET_2-54mm-6-DIP-switch_C54952.pdf | https://lcsc.com/product-detail/DIP-Switches_KE_DSIC06LSGET_2-54mm-6-DIP-switch_C54952.html | 1 | 1
F1 | 1210 (3225) | 1 amp Fast Acting | LittleFuse | LCSC | https://datasheet.lcsc.com/szlcsc/Surface-Mount-Fuses_Littelfuse_0437001-WR_1A-63V_C99537.pdf | https://lcsc.com/product-detail/Surface-Mount-Fuses_Littelfuse_0437001-WR_1A-63V_C99537.html | 1 | 1
F2, F3 | 1210 (3225) | 4 amp Fast Acting | LittleFuse | LCSC | https://datasheet.lcsc.com/szlcsc/Surface-Mount-Fuses_Littelfuse_0437004-WR_4A-32V_C99540.pdf | https://lcsc.com/product-detail/Surface-Mount-Fuses_Littelfuse_0437004-WR_4A-32V_C99540.html | 2 | 1
JP1, JP2 | 3x 2.54 pitch | 2.54mm 1*20P Straight Headers Pins | ReliaPro | LCSC | https://datasheet.lcsc.com/szlcsc/Male-Header_ReliaPro_2-54mm-120PHeader_2-54mm-120P-Straight-HeadersPins_C50981.pdf | https://lcsc.com/product-detail/Male-Header_ReliaPro_2-54mm-120PHeader_2-54mm-120P-Straight-HeadersPins_C50981.html | 2 | 2
2x1 jumper | 2x 2.54 pitch | 2.54mm Short hood | ReliaPro | LCSC | https://datasheet.lcsc.com/szlcsc/Shunts-Jumpers_ReliaPro_2-54mm-Short-hood_2-54mm-Short-hood_C5305.pdf | https://lcsc.com/product-detail/Shunts-Jumpers_ReliaPro_2-54mm-Short-hood_2-54mm-Short-hood_C5305.html | 2 | 2
P1 | 4x 5.08 pitch socket | WJ2EDGVC-5.08-4P | ReliaPro | LCSC | https://datasheet.lcsc.com/szlcsc/2EDG-Connectors_ReliaPro_WJ2EDGVC-5-08-4P_WJ2EDGVC-5-08-4P_C8436.pdf | https://lcsc.com/product-detail/2EDG-Connectors_ReliaPro_WJ2EDGVC-5-08-4P_WJ2EDGVC-5-08-4P_C8436.html | 1 | 1
P1 | 4x 5.08 pitch Connector | WJ2EDGKB-5.08-4P Connector | ReliaPro | LCSC | https://datasheet.lcsc.com/szlcsc/2EDG-Connectors_ReliaPro_WJ2EDGK-5-08-4P-14-00A_WJ2EDGK-5-08-4P_C71372.pdf | https://lcsc.com/product-detail/2EDG-Connectors_ReliaPro_WJ2EDGK-5-08-4P-14-00A_WJ2EDGK-5-08-4P_C71372.html | 1 | 1
P2 | 12x 2.54 pitch | 2.54mm 1*12P Straight Headers Pins | ReliaPro | LCSC | https://datasheet.lcsc.com/szlcsc/Male-Header_ReliaPro_2-54mm-120PHeader_2-54mm-120P-Straight-HeadersPins_C50981.pdf | https://lcsc.com/product-detail/Male-Header_ReliaPro_2-54mm-120PHeader_2-54mm-120P-Straight-HeadersPins_C50981.html | 1 | 1
P3 – P34 | 15x 2.54 pitch | 2.54mm 1*15P Straight Headers female Pins | ReliaPro | LCSC | https://datasheet.lcsc.com/szlcsc/Female-Header_ReliaPro_Female-header1X15P-2-54mm_Female-header-1X15P-2-54mm_C54104.pdf | https://lcsc.com/product-detail/Female-Header_ReliaPro_Female-header1X15P-2-54mm_Female-header-1X15P-2-54mm_C54104.html | 32 | 32
P35, P36 | 15x 2.54 pitch edge |  |  |  |  |  | 2 | 0
R1 | 1206 (3216) |  |  |  |  |  | 1 | 0
R4-R17, R25, R26 | 1206 (3216) | 1 Kohm Current Limters | FH | LCSC | https://datasheet.lcsc.com/szlcsc/Chip-Resistor-Surface-Mount_FH_RS-06K102JT_1K-102-5_C115421.pdf | https://lcsc.com/product-detail/Chip-Resistor-Surface-Mount_FH_RS-06K102JT_1K-102-5_C115421.html | 16 | 16
R18 | 1206 (3216) | 1 Mohm Current Limiter | FH | LCSC | https://datasheet.lcsc.com/szlcsc/Chip-Resistor-Surface-Mount-UniOhm_UniOhm_1206W4F4300T5E_430-4300-1_C17965.pdf | https://lcsc.com/product-detail/Chip-Resistor-Surface-Mount-UniOhm_UniOhm_1206W4F4300T5E_430-4300-1_C17965.html | 1 | 1
R2, R3, R19 – R24 | 1206 (3216) | 430 ohm LED Drivers | Uniroyal | LCSC | https://datasheet.lcsc.com/szlcsc/Chip-Resistor-Surface-Mount-UniOhm_UniOhm_1206W4F4300T5E_430-4300-1_C17965.pdf | https://lcsc.com/product-detail/Chip-Resistor-Surface-Mount-UniOhm_UniOhm_1206W4F4300T5E_430-4300-1_C17965.html | 8 | 8
R27, R29, R31 | 1206 (3216) | Voltage Divider High (R1 = 300 ohm) | FH | LCSC | https://datasheet.lcsc.com/szlcsc/Chip-Resistor-Surface-Mount-UniOhm_UniOhm_1206W4F3000T5E_300-3000-1_C17887.pdf | https://lcsc.com/product-detail/Chip-Resistor-Surface-Mount-UniOhm_UniOhm_1206W4F3000T5E_300-3000-1_C17887.html | 3 | 2
R28, R30, R32 | 1206 (3216) | Voltage Divider Low (R2 = 100ohm) | UniOhm | LCSC | https://datasheet.lcsc.com/szlcsc/Chip-Resistor-Surface-Mount-UniOhm_UniOhm_1206W4F1000T5E_100-1000-1_C17901.pdf | https://lcsc.com/product-detail/Chip-Resistor-Surface-Mount-UniOhm_UniOhm_1206W4F1000T5E_100-1000-1_C17901.html | 3 | 2
R33, R34, R35 | 1206 (3216) | 0ohm jumper for Voltage Regulator Bypass | UniOhm | LCSC | https://datasheet.lcsc.com/szlcsc/Chip-Resistor-Surface-Mount-UniOhm_UniOhm_1206W4J0000T5E_0-0R0-5_C39126.pdf | https://lcsc.com/product-detail/Chip-Resistor-Surface-Mount-UniOhm_UniOhm_1206W4J0000T5E_0-0R0-5_C39126.html | 3 | 0
TVS1, TVS2, TVS3 | SOD323 |  |  |  |  |  | 3 | 0
U1, U3 | To-263-3 | UZ1084 |  | LCSC | https://datasheet.lcsc.com/szlcsc/Linear-Voltage-Regulators_UTC_UZ1084L-AD-TQ3-R_UZ1084L-AD-TQ3-R_C75490.pdf | https://lcsc.com/product-detail/Linear-Voltage-Regulators_UTC_UZ1084L-AD-TQ3-R_UZ1084L-AD-TQ3-R_C75490.html | 2 | 2
U5 | To-263-3 | AMS1084 |  | LCSC | https://datasheet.lcsc.com/szlcsc/Low-Dropout-Regulators-LDO_AMS_AMS1084CM-5-0_AMS1084CM-5-0_C56105.pdf | https://lcsc.com/product-detail/Low-Dropout-Regulators-LDO_AMS_AMS1084CM-5-0_AMS1084CM-5-0_C56105.html | 1 | 1
U2, U4, U6 | T0-220 | LM1084 |  | LCSC | https://datasheet.lcsc.com/szlcsc/Low-Dropout-Regulators-LDO_TI_LM1084IT-ADJ_LM1084IT-ADJ_C9720.pdf | https://lcsc.com/product-detail/Low-Dropout-Regulators-LDO_TI_LM1084IT-ADJ_LM1084IT-ADJ_C9720.html | 3 | 0
Z1, Z2, Z3 | D-SMB | Zener Diodes |  |  |  |  | 3 | 0
HeatSink | To-263-3 – heatsinked | 573300D00000G | Aavid | Mouser | https://www.aavid.com/products/standard/573300d00000g | http://ca.mouser.com/Search/ProductDetail.aspx | 6 | 6
PCB |  |  | EasyEDA | EasyEDA |  | https://easyeda.com | 1 | 1
 |  | Unpopulated (optional)

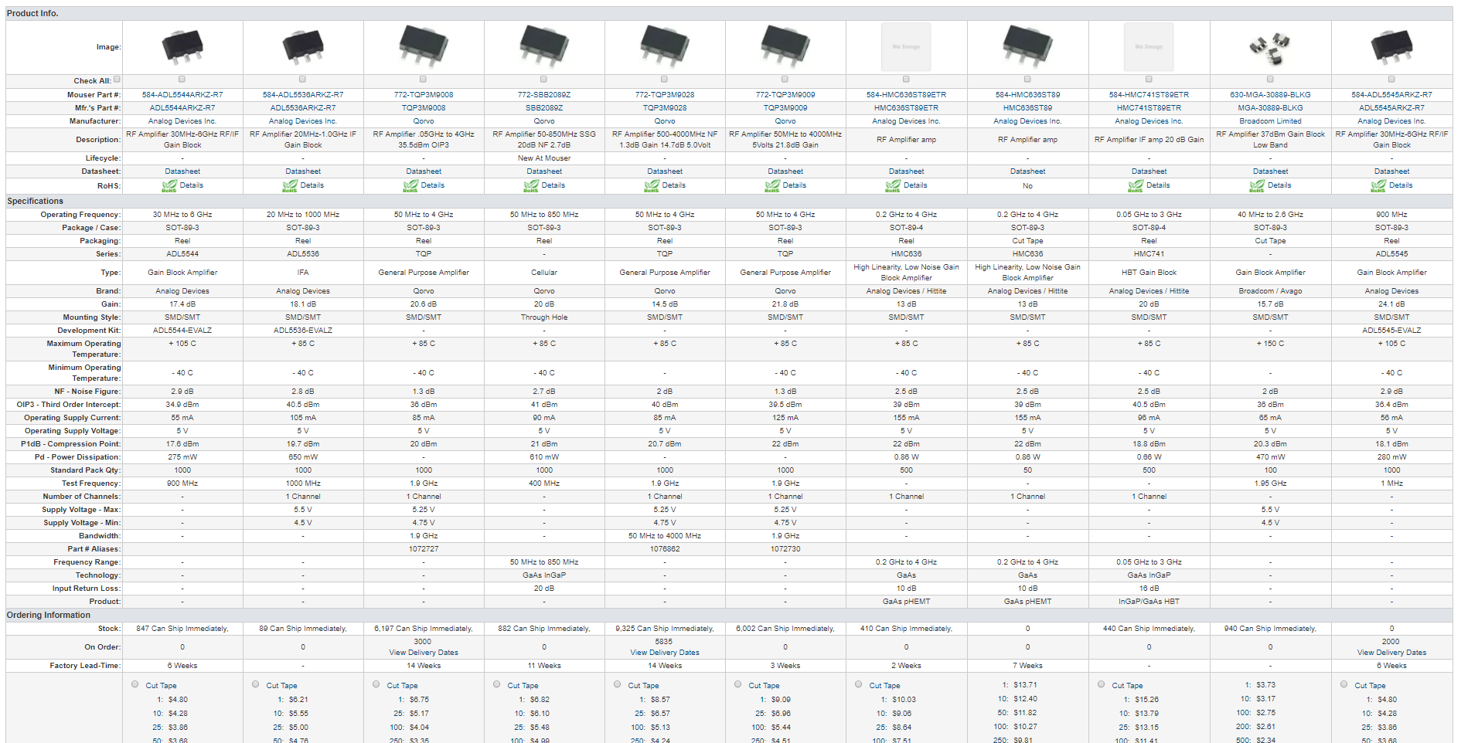
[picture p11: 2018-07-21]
Parts/Mouser_Amps.PNG

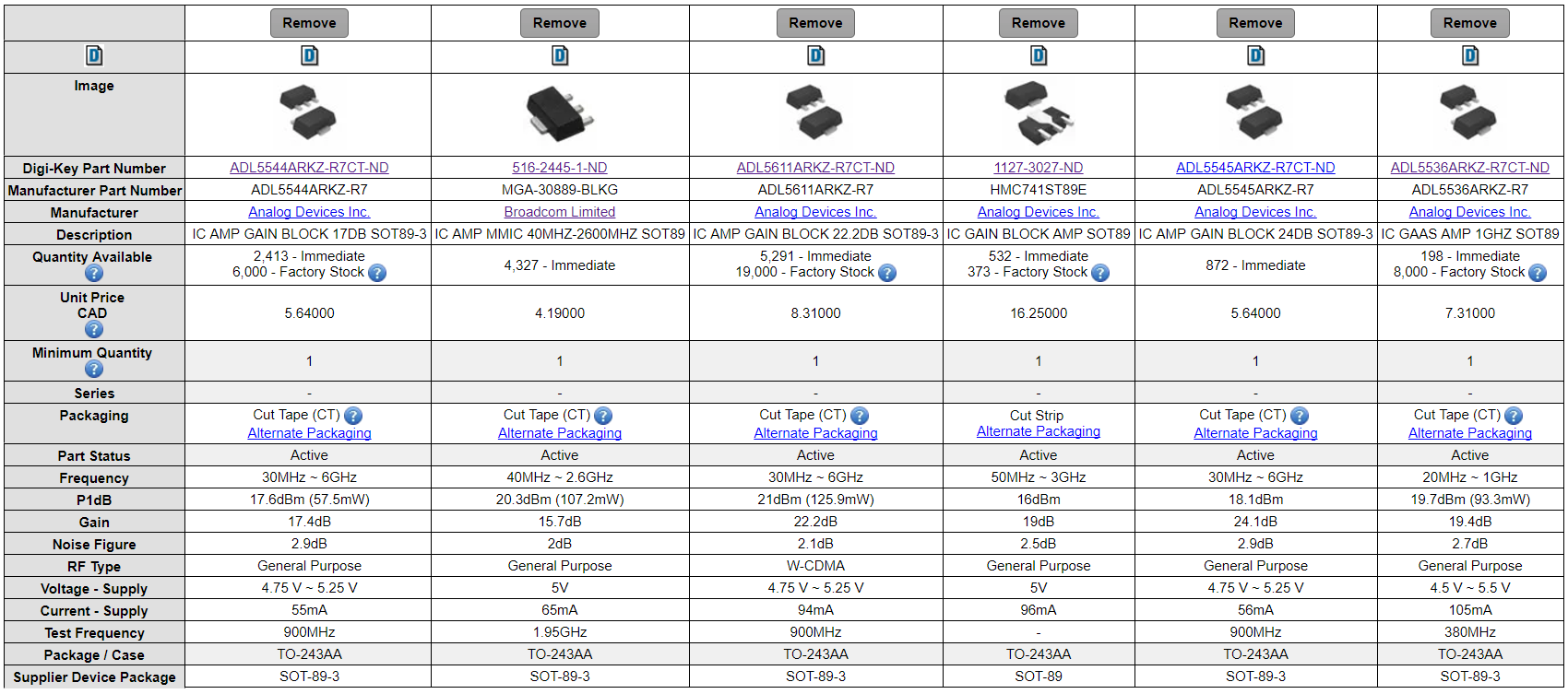
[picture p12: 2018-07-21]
Parts/Digikey_Amps.PNG

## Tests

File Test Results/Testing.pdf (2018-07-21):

Sheet1

Page 1

PCB # | S11 (dB) | s21 (dB) | s12 (dB) | s22 (dB) | S11 (mag) | s21 (mag) | s12 (mag) | s22 (mag) | Delta | K | Gmax (Mag) Gmax (dB)
1 | -19.8 | 15.4 | -20.2 | -15.5 0.102329299 5.888436554 0.097723722 0.167880402 -0.558260853 1.106110285 38.16453414 15.81659966
2 | -20.2 | 15.5 | -20.2 | -15.9 0.097723722 5.956621435 0.097723722 0.160324539 -0.566435707 1.104267669 38.75792595 15.88360529
3 | -19.9 | 15.4 | -20.2 | -15.4 0.101157945 5.888436554 0.097723722 0.169824365 -0.558260853 1.105746971 38.19390254 15.81994036
4 | -19.7 | 15.4 | -20.2 | -15.2 0.103514217 5.888436554 0.097723722 0.173780083 -0.557451228 1.103362036 38.38858687 15.84202125
5 | -19.8 | 15.4 | -20.2 | -15.4 0.102329299 5.888436554 0.097723722 0.169824365 -0.558061929 1.105346913 38.2263288 15.82362591
6 | -19.3 | 15.4 | -20.2 | -15.5 0.108392691 5.888436554 0.097723722 0.167880402 -0.557242929 1.104013464 38.33507972 15.83596371
7 | -20 | 15.4 | -20.3 | -15.6 | 0.1 5.888436554 0.096605088 0.165958691 -0.552257062 1.114036253 37.97662082 15.79516318
8 | -20.1 | 15.5 | -20.3 | -15.5 0.098855309 5.956621435 0.096605088 0.167880402 -0.558844068 1.10728367 38.95696466 15.90585111
9 | -20.1 | 15.4 | -20.2 | -15.4 0.098855309 5.888436554 0.097723722 0.169824365 -0.558651897 1.106526652 38.13096967 15.8127785
10 | -20.5 | 15.5 | -20.2 | -15.9 0.094406088 5.956621435 0.097723722 0.160324539 -0.566967605 1.105333005 38.67011078 15.87375416
11 | -19.6 | 15.5 | -20.2 | -16 0.104712855 5.956621435 0.097723722 0.158489319 -0.565507349 1.10265231 38.89236698 15.89864375
12 | -20 | 15.4 | -20.3 | -15.6 | 0.1 5.888436554 0.096605088 0.165958691 -0.552257062 1.114036253 37.97662082 15.79516318
13 | -19.8 | 15.4 | -20.2 | -16 0.102329299 5.888436554 0.097723722 0.158489319 -0.559221836 1.10970653 37.8778293 15.78385083
14 | -19.7 | 15.4 | -20.2 | -15.7 0.103514217 5.888436554 0.097723722 0.164058977 -0.558457501 1.107191347 38.07759031 15.80669457
15 | -19.7 | 15.4 | -20.3 | -15.7 0.103514217 5.888436554 0.096605088 0.164058977 -0.551870494 1.113583523 38.01169064 15.79917186
16 | -20.2 | 15.4 | -20.3 | -15.1 0.097723722 5.888436554 0.096605088 0.175792361 -0.551673847 1.110912052 38.22081577 15.82299952
17 | -19.2 | 15.4 | -20.2 | -16 0.10964782 5.888436554 0.097723722 0.158489319 -0.558061929 1.107232506 38.07429316 15.8063185
18 | -20.6 | 15.4 | -20.2 | -15.9 0.09332543 5.888436554 0.097723722 0.160324539 -0.560477581 1.111950563 37.7024975 15.7637012
19 | -20 | 15.5 | -20.2 | -16.2 | 0.1 5.956621435 0.097723722 0.154881662 -0.566615052 1.105529267 38.65400559 15.87194505
20 | -19.5 | 15.4 | -20.2 | -15.7 0.105925373 5.888436554 0.097723722 0.164058977 -0.558061929 1.106368798 38.14368308 15.81422625
21 | -20.5 | 15.5 | -20.3 | -15.9 0.094406088 5.956621435 0.096605088 0.160324539 -0.560304325 1.111605561 38.60810734 15.86678512
22 | -19.7 | 15.4 | -20.2 | -15.9 0.103514217 5.888436554 0.097723722 0.160324539 -0.558844068 1.108619214 37.96375877 15.79369205
23 | -20 | 15.4 | -20.3 | -15.7 | 0.1 5.888436554 0.096605088 0.164058977 -0.552447033 1.114771769 37.9198703 15.78866843
24 | -20.2 | 15.4 | -20.2 | -15.5 0.097723722 5.888436554 0.097723722 0.167880402 -0.55903404 1.107661477 38.03998567 15.80240345
25 | -20.1 | 15.4 | -20.2 | -15.7 0.098855309 5.888436554 0.097723722 0.164058977 -0.559221836 1.108752851 37.95316274 15.79247973
26 | -19.6 | 15.4 | -20.2 | -15.6 0.104712855 5.888436554 0.097723722 0.165958691 -0.558061929 1.10604597 38.16972749 15.81719059
27 | -19.8 | 15.4 | -20.3 | -15.5 0.102329299 5.888436554 0.096605088 0.167880402 -0.551673847 1.112492219 38.09666415 15.80886949
28 | -19.9 | 15.4 | -20.2 | -15.9 0.101157945 5.888436554 0.097723722 0.160324539 -0.559221836 1.10940525 37.90157469 15.78657254
29 | -20 | 15.5 | -20.2 | -16 | 0.1 5.956621435 0.097723722 0.158489319 -0.566254286 1.104207134 38.76293589 15.88416663
30 | -20 | 15.5 | -20.2 | -15.6 | 0.1 5.956621435 0.097723722 0.165958691 -0.565507349 1.101399404 38.99773245 15.91039355
31 | -19.7 | 15.4 | -20.2 | -16.2 0.103514217 5.888436554 0.097723722 0.154881662 -0.559407483 1.110657366 37.80321049 15.77528684
32 | -19.7 | 15.4 | -20.2 | -15.7 0.103514217 5.888436554 0.097723722 0.164058977 -0.558457501 1.107191347 38.07759031 15.80669457
Source | -15dbm
Frequency | 200MHz

Formulas from https://www.microwaves101.com/encyclopedias/stability-factor retrieved on sep 6 2017

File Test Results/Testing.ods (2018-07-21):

PCB # | S11 (dB) | s21 (dB) | s12 (dB) | s22 (dB) | S11 (mag) | s21 (mag) | s12 (mag) | s22 (mag) | Delta | K | Gmax (Mag) | Gmax (dB)
1 | -19.8 | 15.4 | -20.2 | -15.5 | 0.102329299228075 | 5.88843655355589 | 0.097723722095581 | 0.167880401812256 | -0.558260853465581 | 1.10611028460221 | 38.1645341426298 | 15.816599655118
2 | -20.2 | 15.5 | -20.2 | -15.9 | 0.097723722095581 | 5.9566214352901 | 0.097723722095581 | 0.160324539069004 | -0.56643570706979 | 1.1042676687812 | 38.757925951966 | 15.8836052865435
3 | -19.9 | 15.4 | -20.2 | -15.4 | 0.10115794542599 | 5.88843655355589 | 0.097723722095581 | 0.169824365246174 | -0.558260853465581 | 1.10574697113213 | 38.1939025353473 | 15.8199403551332
4 | -19.7 | 15.4 | -20.2 | -15.2 | 0.103514216667934 | 5.88843655355589 | 0.097723722095581 | 0.173780082874938 | -0.557451228185869 | 1.10336203585877 | 38.3885868656758 | 15.8420212546112
5 | -19.8 | 15.4 | -20.2 | -15.4 | 0.102329299228075 | 5.88843655355589 | 0.097723722095581 | 0.169824365246174 | -0.558061929049663 | 1.10534691251148 | 38.2263287960636 | 15.8236259097822
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

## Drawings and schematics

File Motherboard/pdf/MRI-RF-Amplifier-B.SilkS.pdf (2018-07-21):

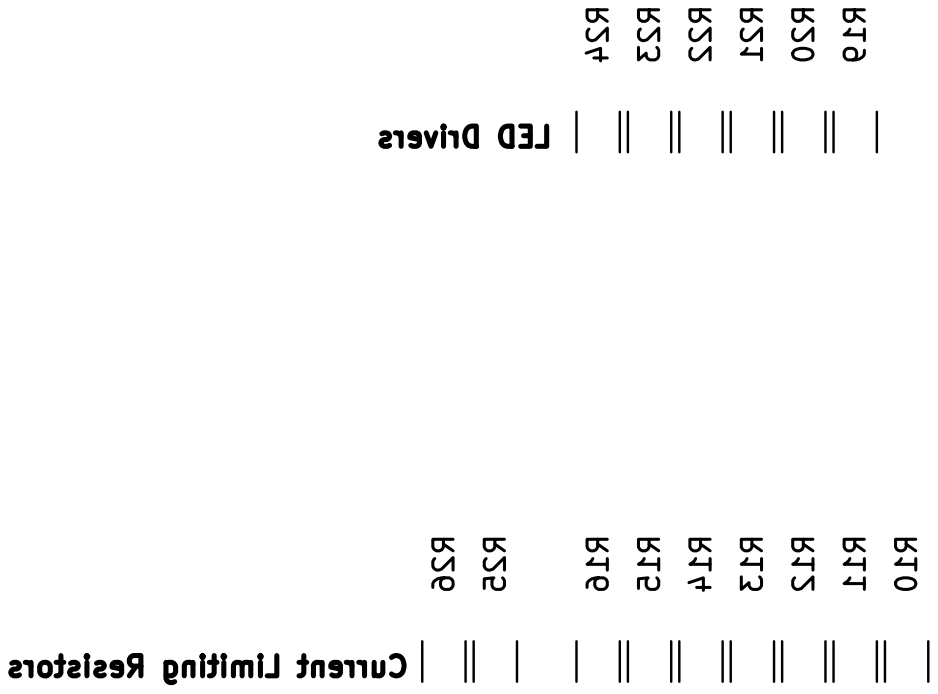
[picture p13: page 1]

Current Limiting Resistors LED Drivers R16 R15 R14 R13 R12 R11 R10 R24 R23 R22 R21 R20 R19 R26 R25

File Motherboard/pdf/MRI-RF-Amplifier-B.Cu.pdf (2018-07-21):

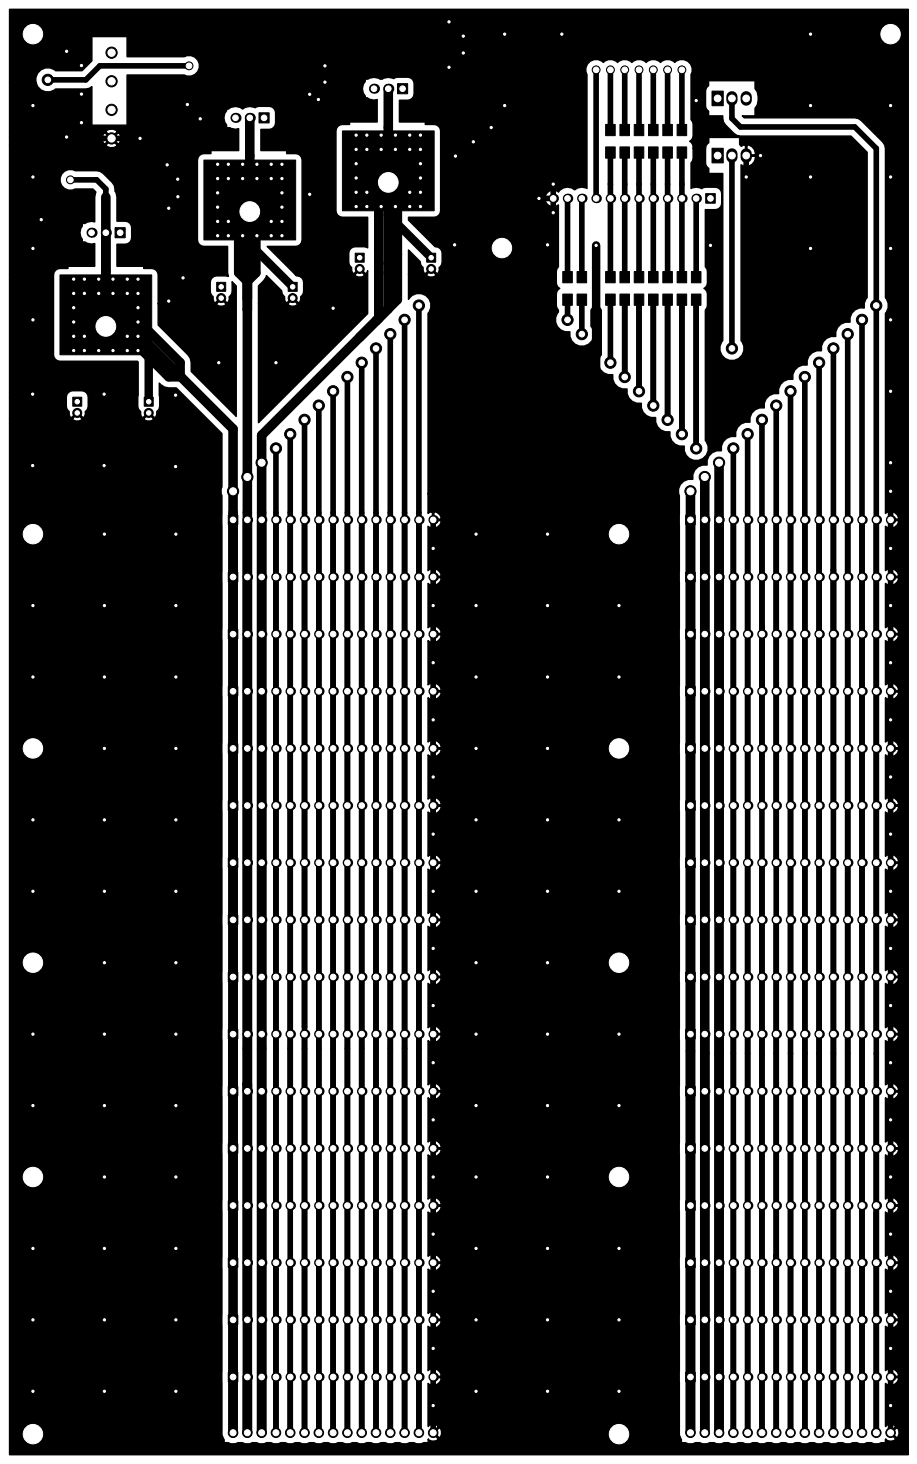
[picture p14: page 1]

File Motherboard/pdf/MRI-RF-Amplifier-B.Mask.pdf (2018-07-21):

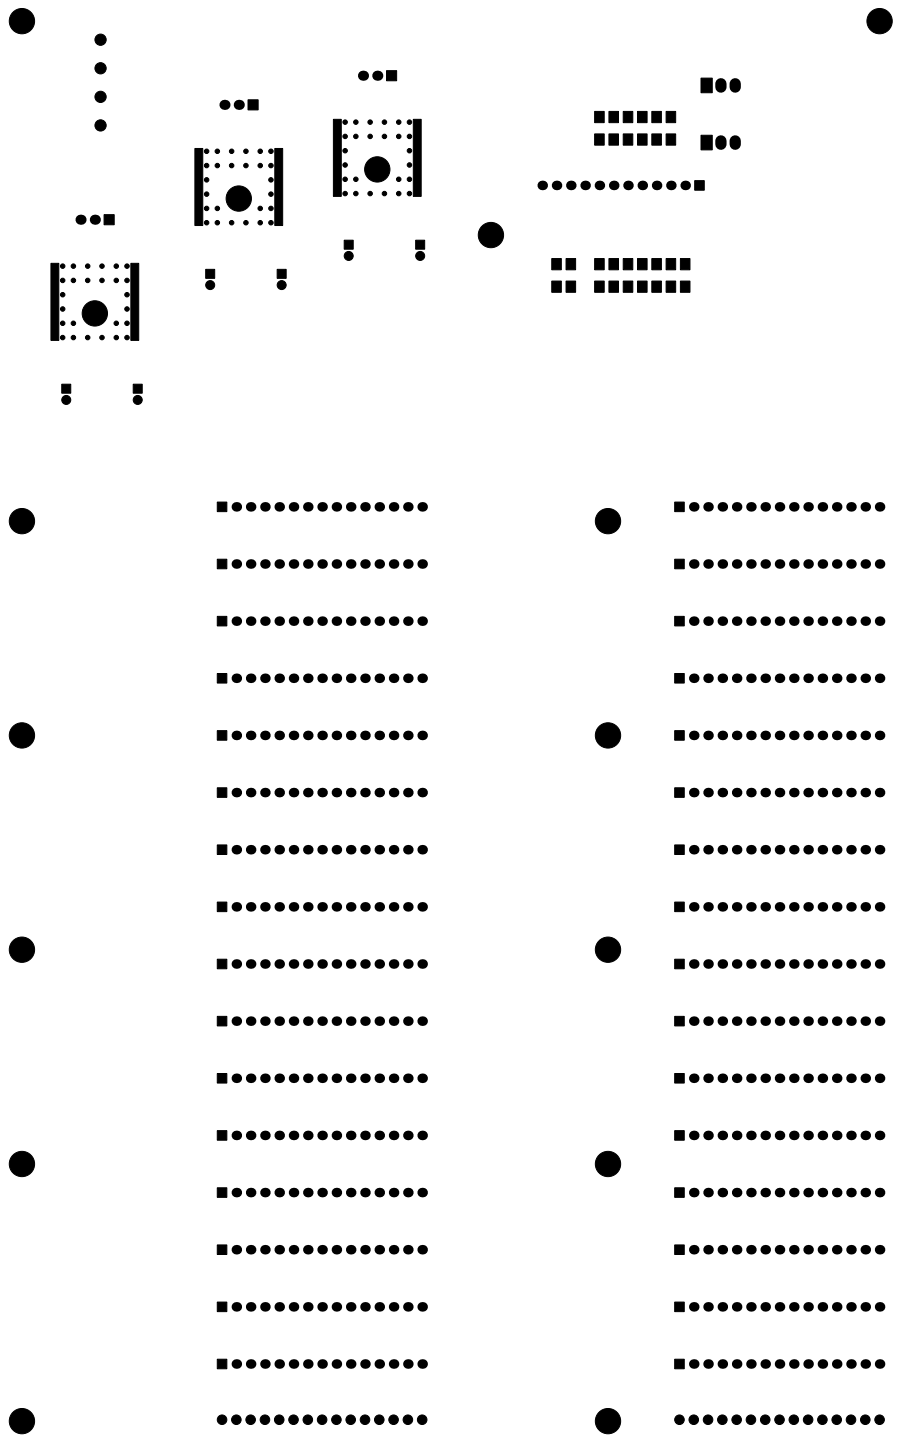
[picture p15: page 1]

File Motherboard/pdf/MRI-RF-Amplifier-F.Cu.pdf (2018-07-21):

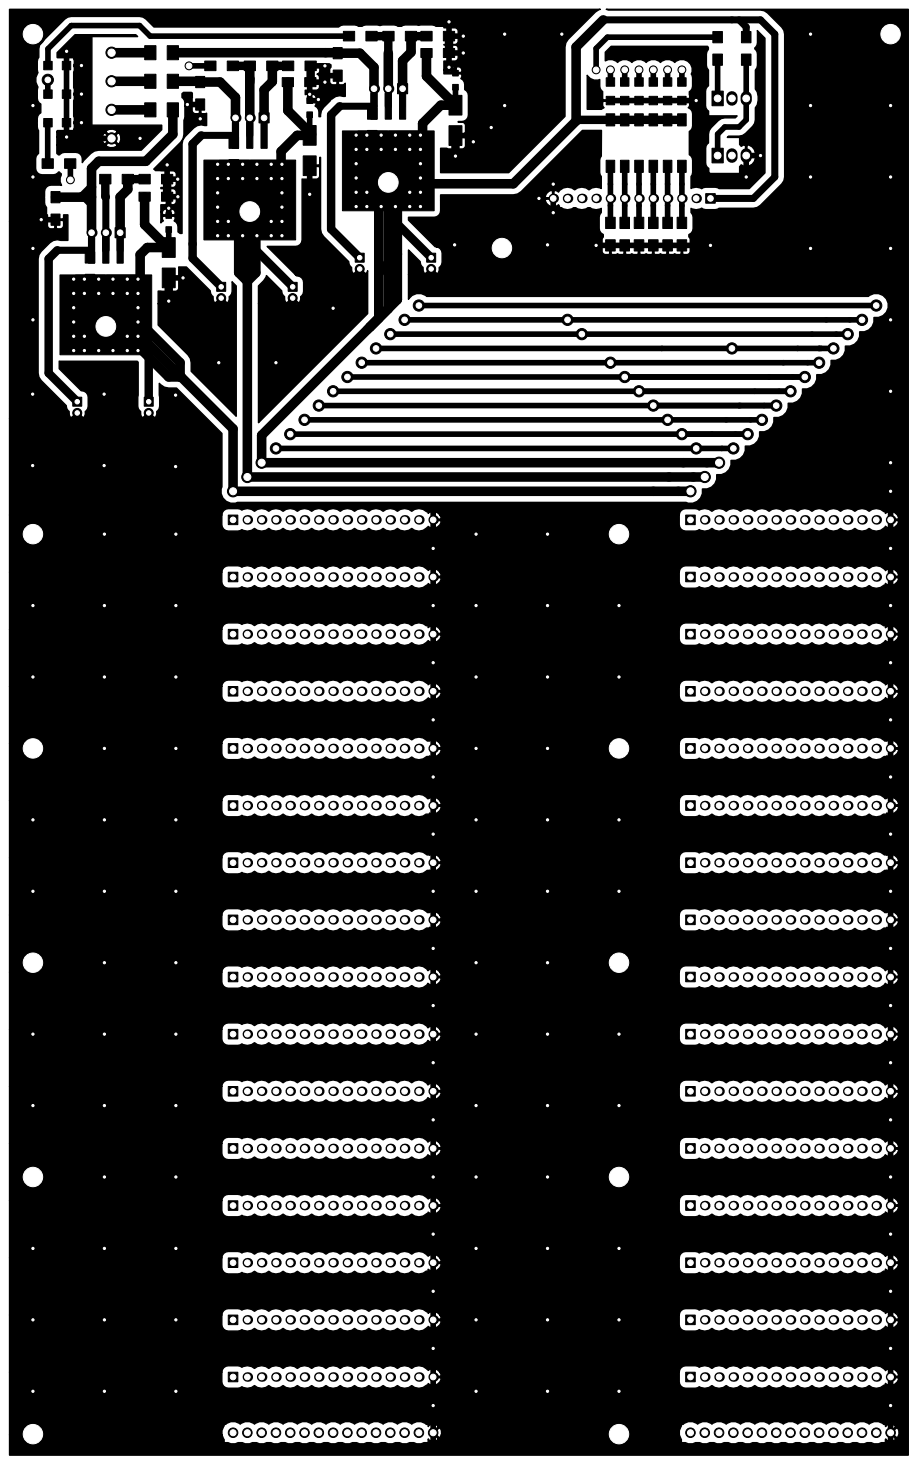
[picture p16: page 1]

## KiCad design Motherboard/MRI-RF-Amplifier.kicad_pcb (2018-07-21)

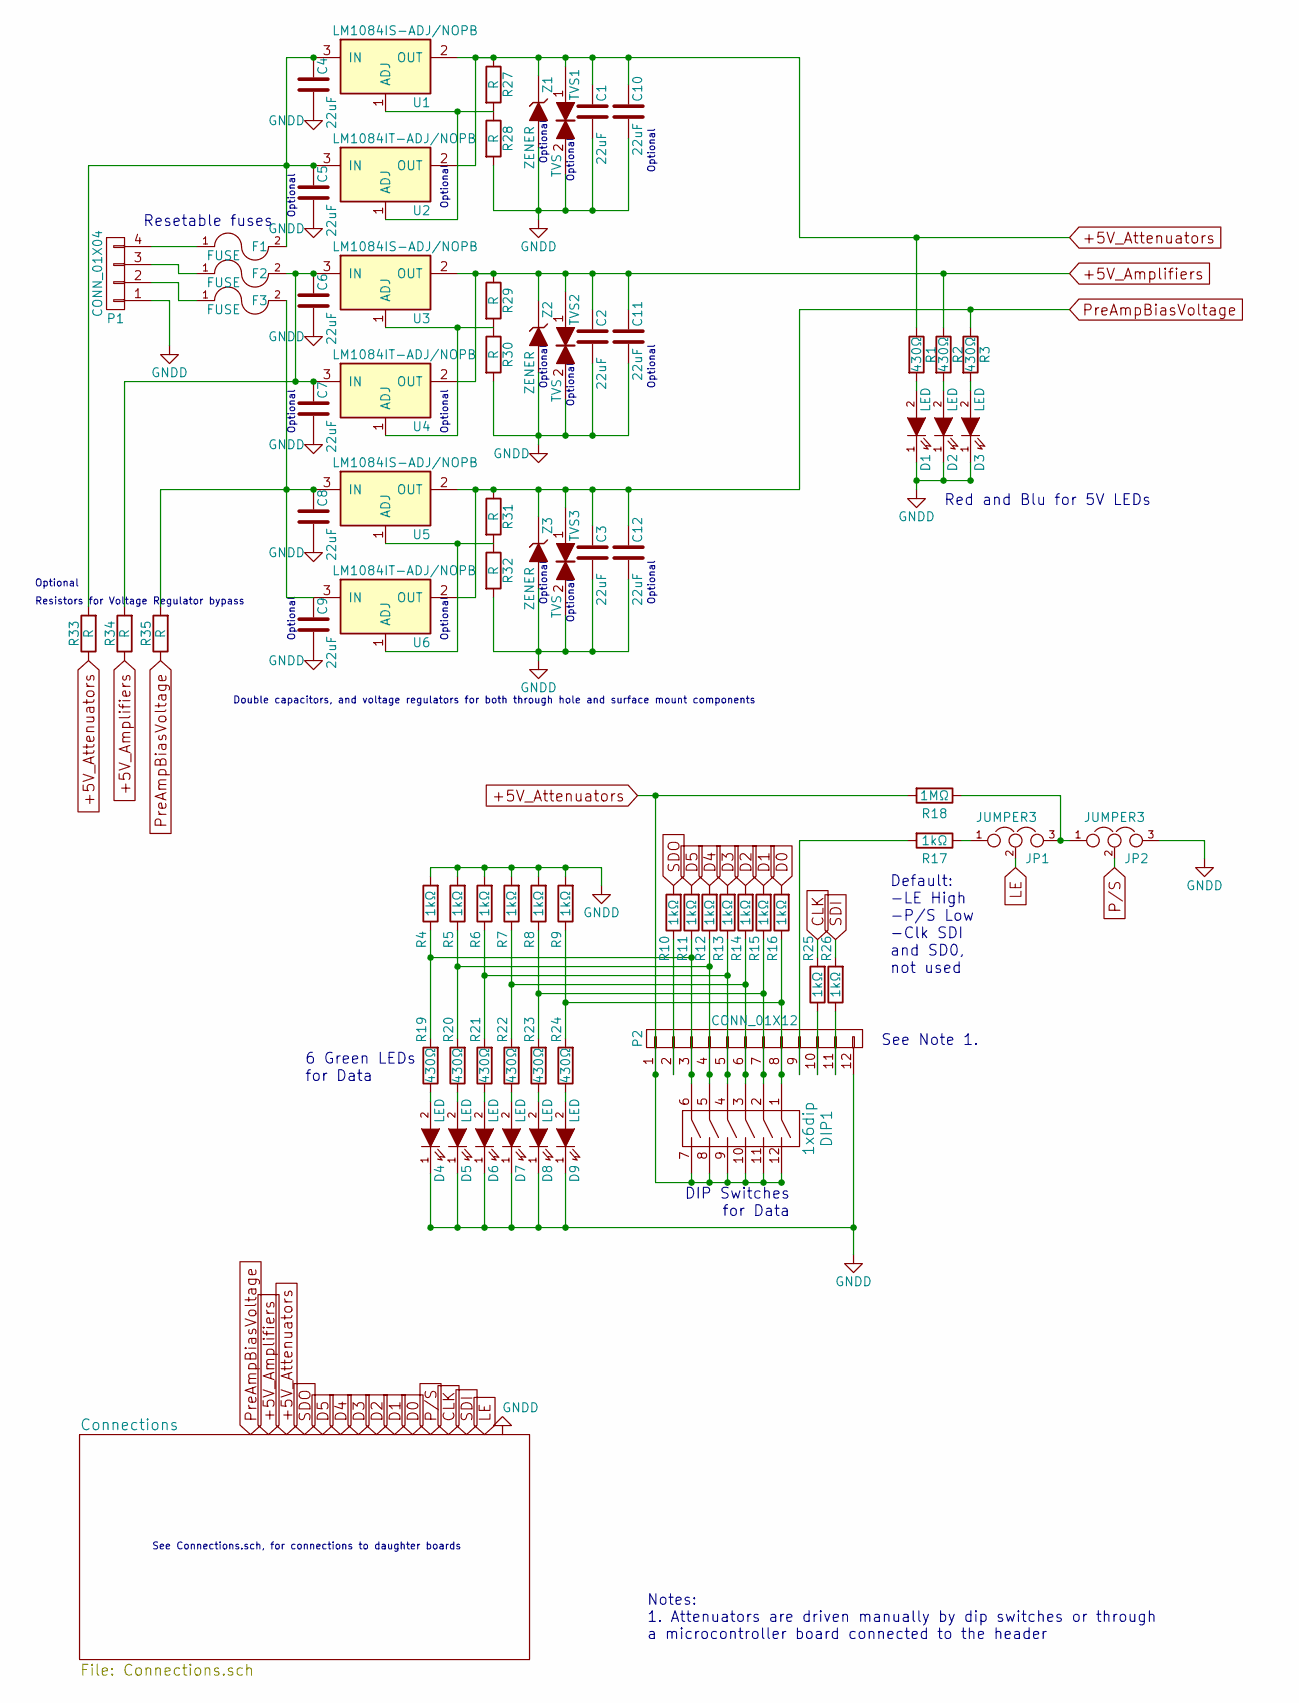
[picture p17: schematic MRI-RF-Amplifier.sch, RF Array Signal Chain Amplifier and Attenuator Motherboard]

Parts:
C1, C2, C3, C4, C6, C8: 22uF; C_1206_HandSoldering
C5, C7, C9, C10, C11, C12: 22uF; CP_Radial_D5.0mm_P2.00mm
D1, D2, D3, D4, D5, D6, D7, D8, D9: LED; LED_1206
DIP1: 1x6dip; DIP_SPSTx6
F1, F2, F3: FUSE; C_1210_HandSoldering
JP1, JP2: JUMPER3; Molex_KK-6410-03_03x2.54mm_Straight
P1: CONN_01X04; OSTTC0421162
P2: CONN_01X12; Pin_Header_Straight_1x12_Pitch2.54mm
R1, R2, R3, R19, R20, R21, R22, R23, R24: 430Ω; R_1206_HandSoldering
R4, R5, R6, R7, R8, R9, R10, R11, R12, R13, R14, R15, R16, R17, R25, R26: 1kΩ; R_1206_HandSoldering
R18: 1MΩ; R_1206_HandSoldering
R27, R28, R29, R30, R31, R32, R33, R34, R35: R; R_1206_HandSoldering
TVS1, TVS2, TVS3: TVS; D_SOD-323_HandSoldering
U1, U3, U5: LM1084IS-ADJ/NOPB; TO-263-3_TabPin2
U2, U4, U6: LM1084IT-ADJ/NOPB; TO-220_Horizontal
Z1, Z2, Z3: ZENER; D_SMB_Handsoldering

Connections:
+5V_Amplifiers: C2.1, C11.1, R2.1, R29.1, R34.1, TVS2.1, U3.2 (OUT), U4.2 (OUT), Z2.1 (K); also elsewhere on the board
+5V_Attenuators: C1.1, C10.1, DIP1.7, DIP1.8, DIP1.9, DIP1.10, DIP1.11, DIP1.12, P2.1, R1.1, R18.2, R27.1, R33.1, TVS1.1, U1.2 (OUT), U2.2 (OUT), Z1.1 (K); also elsewhere on the board
CLK: R25.2; also elsewhere on the board
D0: R16.2; also elsewhere on the board
D1: R15.2; also elsewhere on the board
D2: R14.2; also elsewhere on the board
D3: R13.2; also elsewhere on the board
D4: R12.2; also elsewhere on the board
D5: R11.2; also elsewhere on the board
GNDD: C1.2, C2.2, C3.2, C4.2, C5.2, C6.2, C7.2, C8.2, C9.2, C10.2, C11.2, C12.2, D1.1 (K), D2.1 (K), D3.1 (K), D4.1 (K), D5.1 (K), D6.1 (K), D7.1 (K), D8.1 (K), D9.1 (K), JP2.3, P1.1, P2.12, R4.2, R5.2, R6.2, R7.2, R8.2, R9.2, R28.2, R30.2, R32.2, TVS1.2, TVS2.2, TVS3.2, Z1.2 (A), Z2.2 (A), Z3.2 (A); also elsewhere on the board
LE: JP1.2; also elsewhere on the board
unnamed: C4.1, C5.1, F1.2, R33.2, U1.3 (IN), U2.3 (IN)
unnamed: C6.1, C7.1, F2.2, R34.2, U3.3 (IN), U4.3 (IN)
unnamed: C8.1, C9.1, F3.2, R35.2, U5.3 (IN), U6.3 (IN)
unnamed: D1.2 (A), R1.2
unnamed: D2.2 (A), R2.2
unnamed: D3.2 (A), R3.2
unnamed: D4.2 (A), R19.1
unnamed: D5.2 (A), R20.1
unnamed: D6.2 (A), R21.1
unnamed: D7.2 (A), R22.1
unnamed: D8.2 (A), R23.1
unnamed: D9.2 (A), R24.1
unnamed: DIP1.1, P2.8, R9.1, R16.1, R24.2
unnamed: DIP1.2, P2.7, R8.1, R15.1, R23.2
unnamed: DIP1.3, P2.6, R7.1, R14.1, R22.2
unnamed: DIP1.4, P2.5, R6.1, R13.1, R21.2
unnamed: DIP1.5, P2.4, R5.1, R12.1, R20.2
unnamed: DIP1.6, P2.3, R4.1, R11.1, R19.2
unnamed: F1.1, P1.4
unnamed: F2.1, P1.3
unnamed: F3.1, P1.2
unnamed: JP1.1, R17.1
unnamed: JP1.3, JP2.1, R18.1
unnamed: P2.2, R10.1
unnamed: P2.9, R17.2
unnamed: P2.10, R25.1
unnamed: P2.11, R26.1
unnamed: R27.2, R28.1, U1.1 (ADJ), U2.1 (ADJ)
unnamed: R29.2, R30.1, U3.1 (ADJ), U4.1 (ADJ)
unnamed: R31.2, R32.1, U5.1 (ADJ), U6.1 (ADJ)
P/S: JP2.2; also elsewhere on the board
PreAmpBiasVoltage: C3.1, C12.1, R3.1, R31.1, R35.1, TVS3.1, U5.2 (OUT), U6.2 (OUT), Z3.1 (K); also elsewhere on the board
SDI: R26.2; also elsewhere on the board
SDO: R10.2; also elsewhere on the board

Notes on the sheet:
Notes: 1. Attenuators are driven manually by dip switches or through a microcontroller board connected to the header
6 Green LEDs for Data
DIP Switches for Data
Default: -LE High -P/S Low -Clk SDI and SD0, not used
Resetable fuses
See Note 1.
Red and Blu for 5V LEDs
See Connections.sch, for connections to daughter boards
Double capacitors, and voltage regulators for both through hole and surface mount components
Resistors for Voltage Regulator bypass
Optional

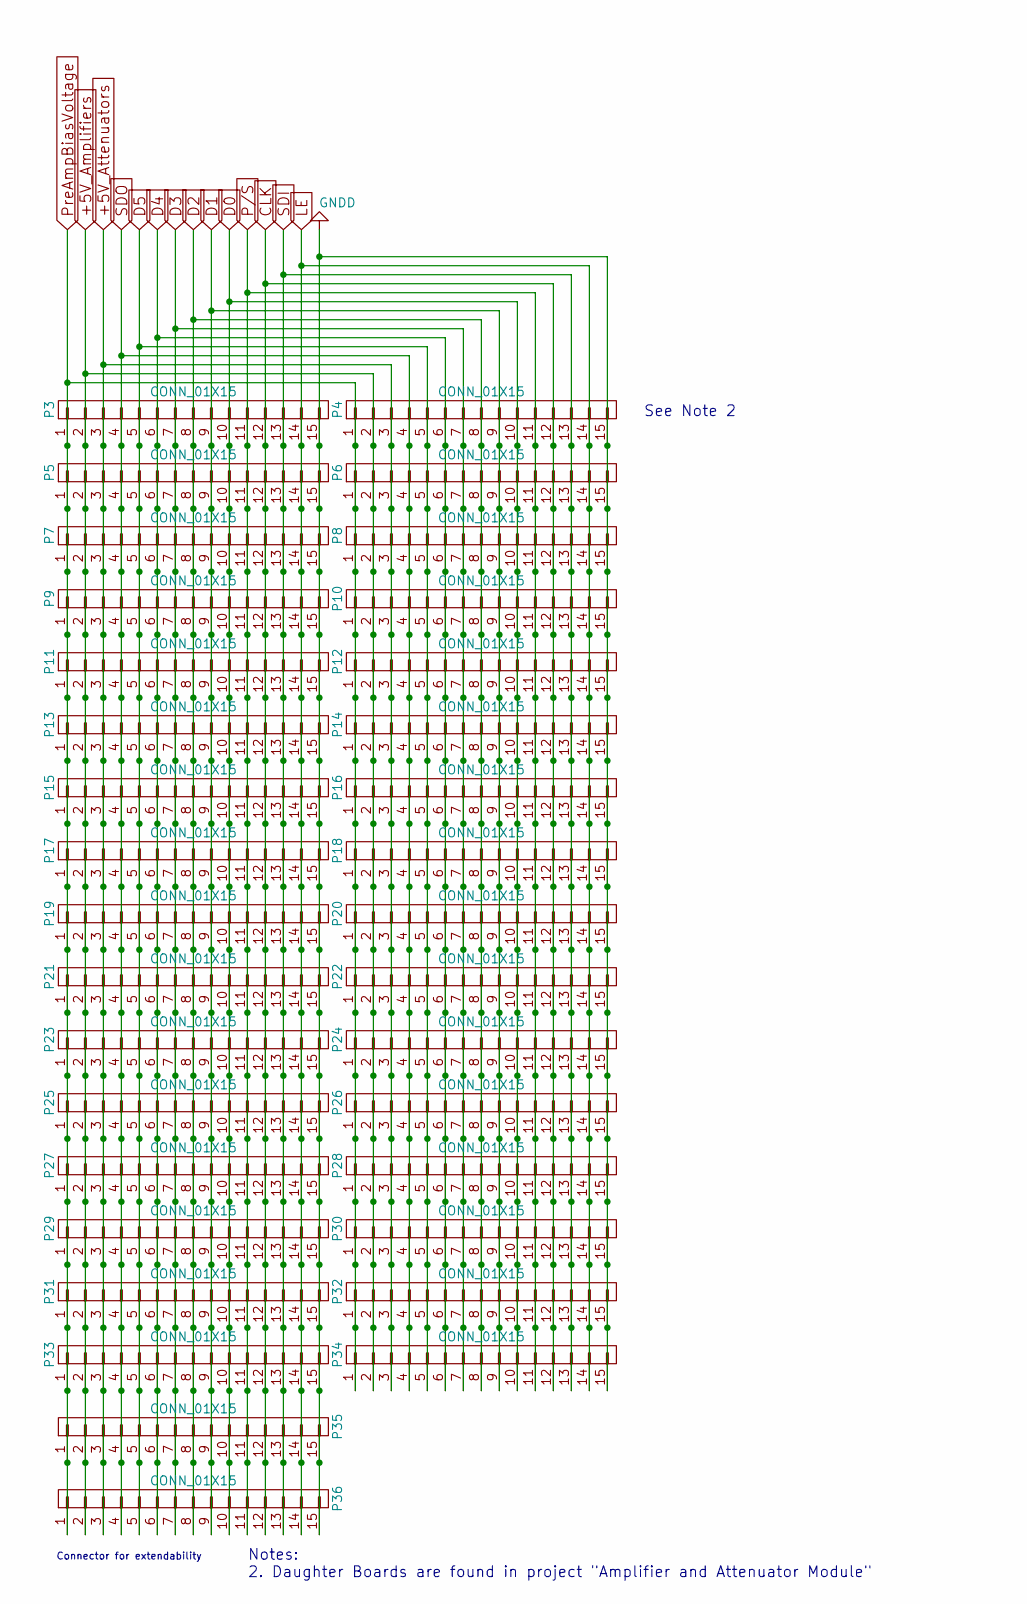
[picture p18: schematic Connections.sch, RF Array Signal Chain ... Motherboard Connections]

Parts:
P3, P4, P5, P6, P7, P8, P9, P10, P11, P12, P13, P14, P15, P16, P17, P18, P19, P20, P21, P22, P23, P24, P25, P26, P27, P28, P29, P30, P31, P32, P33, P34: CONN_01X15; Pin_Header_Straight_1x15_Pitch2.54mm
P35, P36: CONN_01X15; Molex_kk4455_Edge_01x15

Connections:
+5V_Amplifiers: P3.2, P4.2, P5.2, P6.2, P7.2, P8.2, P9.2, P10.2, P11.2, P12.2, P13.2, P14.2, P15.2, P16.2, P17.2, P18.2, P19.2, P20.2, P21.2, P22.2, P23.2, P24.2, P25.2, P26.2, P27.2, P28.2, P29.2, P30.2, P31.2, P32.2, P33.2, P34.2, P35.2, P36.2; also elsewhere on the board
+5V_Attenuators: P3.3, P4.3, P5.3, P6.3, P7.3, P8.3, P9.3, P10.3, P11.3, P12.3, P13.3, P14.3, P15.3, P16.3, P17.3, P18.3, P19.3, P20.3, P21.3, P22.3, P23.3, P24.3, P25.3, P26.3, P27.3, P28.3, P29.3, P30.3, P31.3, P32.3, P33.3, P34.3, P35.3, P36.3; also elsewhere on the board
CLK: P3.12, P4.12, P5.12, P6.12, P7.12, P8.12, P9.12, P10.12, P11.12, P12.12, P13.12, P14.12, P15.12, P16.12, P17.12, P18.12, P19.12, P20.12, P21.12, P22.12, P23.12, P24.12, P25.12, P26.12, P27.12, P28.12, P29.12, P30.12, P31.12, P32.12, P33.12, P34.12, P35.12, P36.12; also elsewhere on the board
D0: P3.10, P4.10, P5.10, P6.10, P7.10, P8.10, P9.10, P10.10, P11.10, P12.10, P13.10, P14.10, P15.10, P16.10, P17.10, P18.10, P19.10, P20.10, P21.10, P22.10, P23.10, P24.10, P25.10, P26.10, P27.10, P28.10, P29.10, P30.10, P31.10, P32.10, P33.10, P34.10, P35.10, P36.10; also elsewhere on the board
D1: P3.9, P4.9, P5.9, P6.9, P7.9, P8.9, P9.9, P10.9, P11.9, P12.9, P13.9, P14.9, P15.9, P16.9, P17.9, P18.9, P19.9, P20.9, P21.9, P22.9, P23.9, P24.9, P25.9, P26.9, P27.9, P28.9, P29.9, P30.9, P31.9, P32.9, P33.9, P34.9, P35.9, P36.9; also elsewhere on the board
D2: P3.8, P4.8, P5.8, P6.8, P7.8, P8.8, P9.8, P10.8, P11.8, P12.8, P13.8, P14.8, P15.8, P16.8, P17.8, P18.8, P19.8, P20.8, P21.8, P22.8, P23.8, P24.8, P25.8, P26.8, P27.8, P28.8, P29.8, P30.8, P31.8, P32.8, P33.8, P34.8, P35.8, P36.8; also elsewhere on the board
D3: P3.7, P4.7, P5.7, P6.7, P7.7, P8.7, P9.7, P10.7, P11.7, P12.7, P13.7, P14.7, P15.7, P16.7, P17.7, P18.7, P19.7, P20.7, P21.7, P22.7, P23.7, P24.7, P25.7, P26.7, P27.7, P28.7, P29.7, P30.7, P31.7, P32.7, P33.7, P34.7, P35.7, P36.7; also elsewhere on the board
D4: P3.6, P4.6, P5.6, P6.6, P7.6, P8.6, P9.6, P10.6, P11.6, P12.6, P13.6, P14.6, P15.6, P16.6, P17.6, P18.6, P19.6, P20.6, P21.6, P22.6, P23.6, P24.6, P25.6, P26.6, P27.6, P28.6, P29.6, P30.6, P31.6, P32.6, P33.6, P34.6, P35.6, P36.6; also elsewhere on the board
D5: P3.5, P4.5, P5.5, P6.5, P7.5, P8.5, P9.5, P10.5, P11.5, P12.5, P13.5, P14.5, P15.5, P16.5, P17.5, P18.5, P19.5, P20.5, P21.5, P22.5, P23.5, P24.5, P25.5, P26.5, P27.5, P28.5, P29.5, P30.5, P31.5, P32.5, P33.5, P34.5, P35.5, P36.5; also elsewhere on the board
GNDD: P3.15, P4.15, P5.15, P6.15, P7.15, P8.15, P9.15, P10.15, P11.15, P12.15, P13.15, P14.15, P15.15, P16.15, P17.15, P18.15, P19.15, P20.15, P21.15, P22.15, P23.15, P24.15, P25.15, P26.15, P27.15, P28.15, P29.15, P30.15, P31.15, P32.15, P33.15, P34.15, P35.15, P36.15; also elsewhere on the board
LE: P3.14, P4.14, P5.14, P6.14, P7.14, P8.14, P9.14, P10.14, P11.14, P12.14, P13.14, P14.14, P15.14, P16.14, P17.14, P18.14, P19.14, P20.14, P21.14, P22.14, P23.14, P24.14, P25.14, P26.14, P27.14, P28.14, P29.14, P30.14, P31.14, P32.14, P33.14, P34.14, P35.14, P36.14; also elsewhere on the board
P/S: P3.11, P4.11, P5.11, P6.11, P7.11, P8.11, P9.11, P10.11, P11.11, P12.11, P13.11, P14.11, P15.11, P16.11, P17.11, P18.11, P19.11, P20.11, P21.11, P22.11, P23.11, P24.11, P25.11, P26.11, P27.11, P28.11, P29.11, P30.11, P31.11, P32.11, P33.11, P34.11, P35.11, P36.11; also elsewhere on the board
PreAmpBiasVoltage: P3.1, P4.1, P5.1, P6.1, P7.1, P8.1, P9.1, P10.1, P11.1, P12.1, P13.1, P14.1, P15.1, P16.1, P17.1, P18.1, P19.1, P20.1, P21.1, P22.1, P23.1, P24.1, P25.1, P26.1, P27.1, P28.1, P29.1, P30.1, P31.1, P32.1, P33.1, P34.1, P35.1, P36.1; also elsewhere on the board
SDI: P3.13, P4.13, P5.13, P6.13, P7.13, P8.13, P9.13, P10.13, P11.13, P12.13, P13.13, P14.13, P15.13, P16.13, P17.13, P18.13, P19.13, P20.13, P21.13, P22.13, P23.13, P24.13, P25.13, P26.13, P27.13, P28.13, P29.13, P30.13, P31.13, P32.13, P33.13, P34.13, P35.13, P36.13; also elsewhere on the board
SDO: P3.4, P4.4, P5.4, P6.4, P7.4, P8.4, P9.4, P10.4, P11.4, P12.4, P13.4, P14.4, P15.4, P16.4, P17.4, P18.4, P19.4, P20.4, P21.4, P22.4, P23.4, P24.4, P25.4, P26.4, P27.4, P28.4, P29.4, P30.4, P31.4, P32.4, P33.4, P34.4, P35.4, P36.4; also elsewhere on the board

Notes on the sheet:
Connector for extendability
Notes: 2. Daughter Boards are found in project "Amplifier and Attenuator Module"
See Note 2

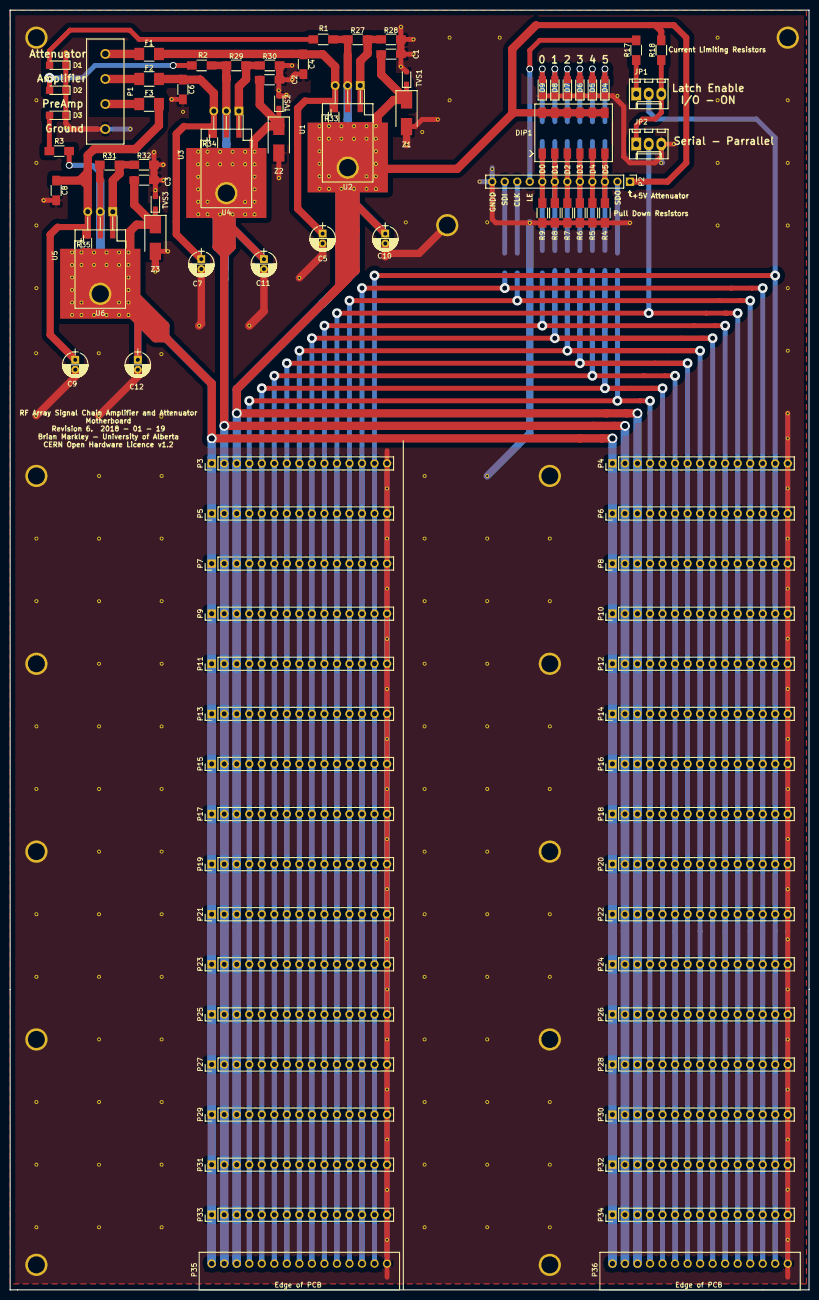
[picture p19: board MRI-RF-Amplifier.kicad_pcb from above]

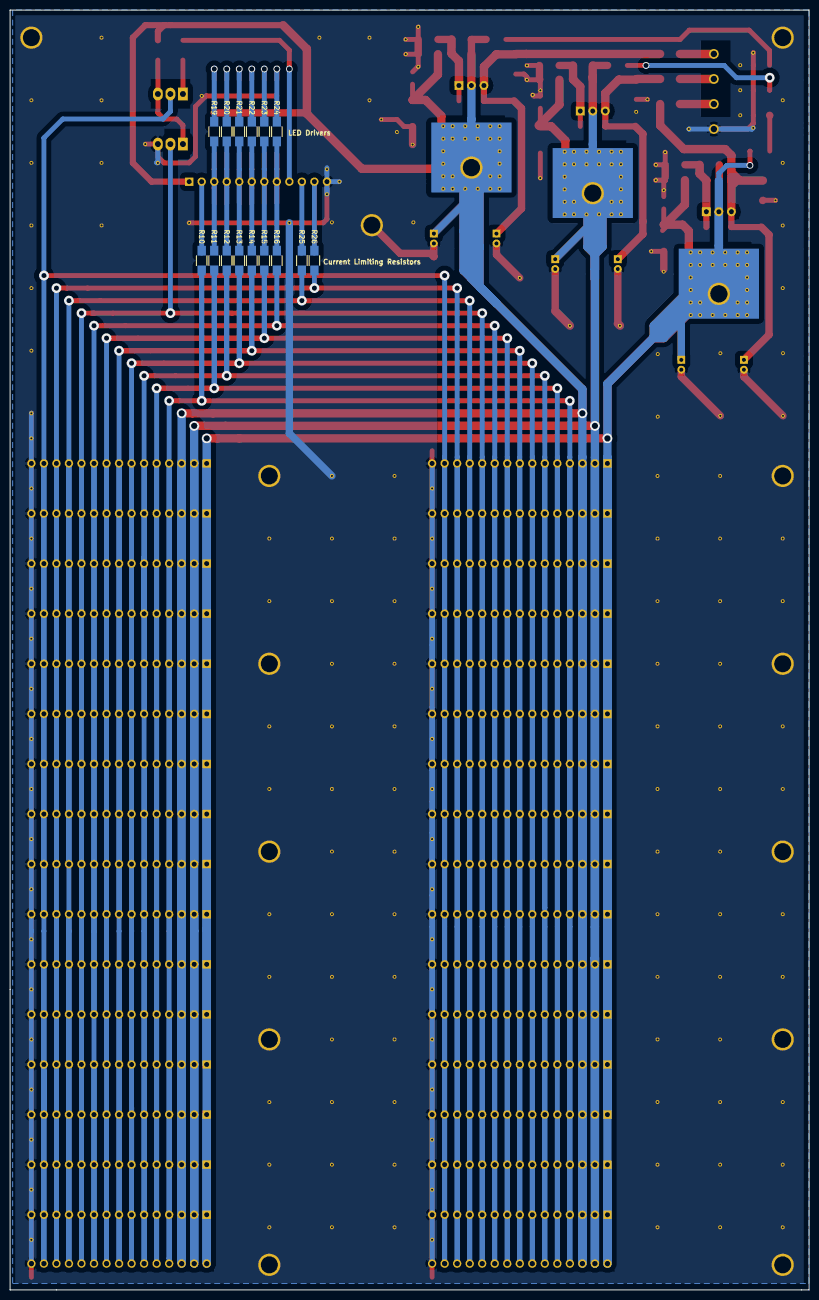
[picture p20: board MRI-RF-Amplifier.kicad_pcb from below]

Board: 2 copper layers, 162.1 x 259.6 mm, 110 parts (15 on the bottom side), 45 nets.

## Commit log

2018-07-21 Daughterboard Files
    [Amplifier and Attenuator Module.kicad_pcb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]
2018-07-21 Motherboard Files
    [Connections.sch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]
2018-07-21 Parts Lists and Component Datasheets
    [Mouser Amp Comparison.ods, Parts Daughter.ods, Parts Mother.ods]
2018-07-21 Test Results
    [Testing.ods]
